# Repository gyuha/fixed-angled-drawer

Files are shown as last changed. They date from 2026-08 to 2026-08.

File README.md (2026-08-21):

# fixed-angled-drawer — 적층형 경사 필통

책상 모서리에 클램프로 고정하고, 같은 규격의 모듈을 위로 계속 쌓아 올리는 경사형 필통입니다.
FreeCAD 파이썬 스크립트 하나(`pen_holder.py`)가 모든 부품을 파라메트릭하게 생성하고, 치수·형상·출력성을 자체 검증합니다.

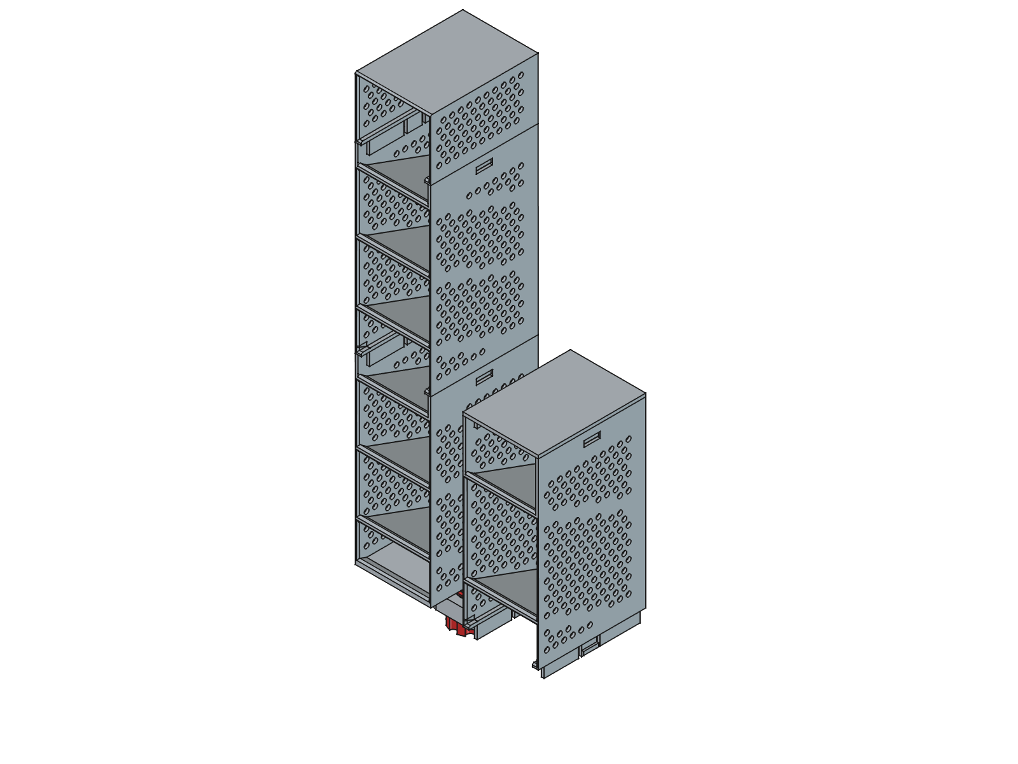
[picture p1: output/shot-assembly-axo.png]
조립 상태


## 특징

- **흔들리지 않는 고정** — 1단 뒷면에 책상 모서리를 감싸는 ㄷ자 클램프가 일체로 붙어 있고, 썸스크류로 상판을 물어 조입니다. 높이 쌓아도 흔들리지 않습니다.
- **무한 적층** — 모든 모듈의 높이(170mm)와 결합 인터페이스가 동일해서, 2칸·3칸 모듈을 어떤 순서로든 원하는 높이까지 쌓을 수 있습니다. 맨 위는 마감 모듈이나 평판 뚜껑으로 닫습니다.
- **적층 시 공간이 이어짐** — 적층 모듈의 하단이 열려 있어, 아래 모듈의 맨 위 칸과 공간이 연결됩니다. 긴 자·붓도 걸리지 않습니다.
- **서포트 없이 출력** — 뒷면을 베드에 대면 앞턱·클램프·결합부가 모두 자기지지 형상이라 서포트가 사실상 필요 없습니다.
- **측벽 타공** — 벌집 배열 타공이 측벽의 빈 영역에만 들어가 밋밋함을 덜고 무게를 줄입니다.

## 부품 구성

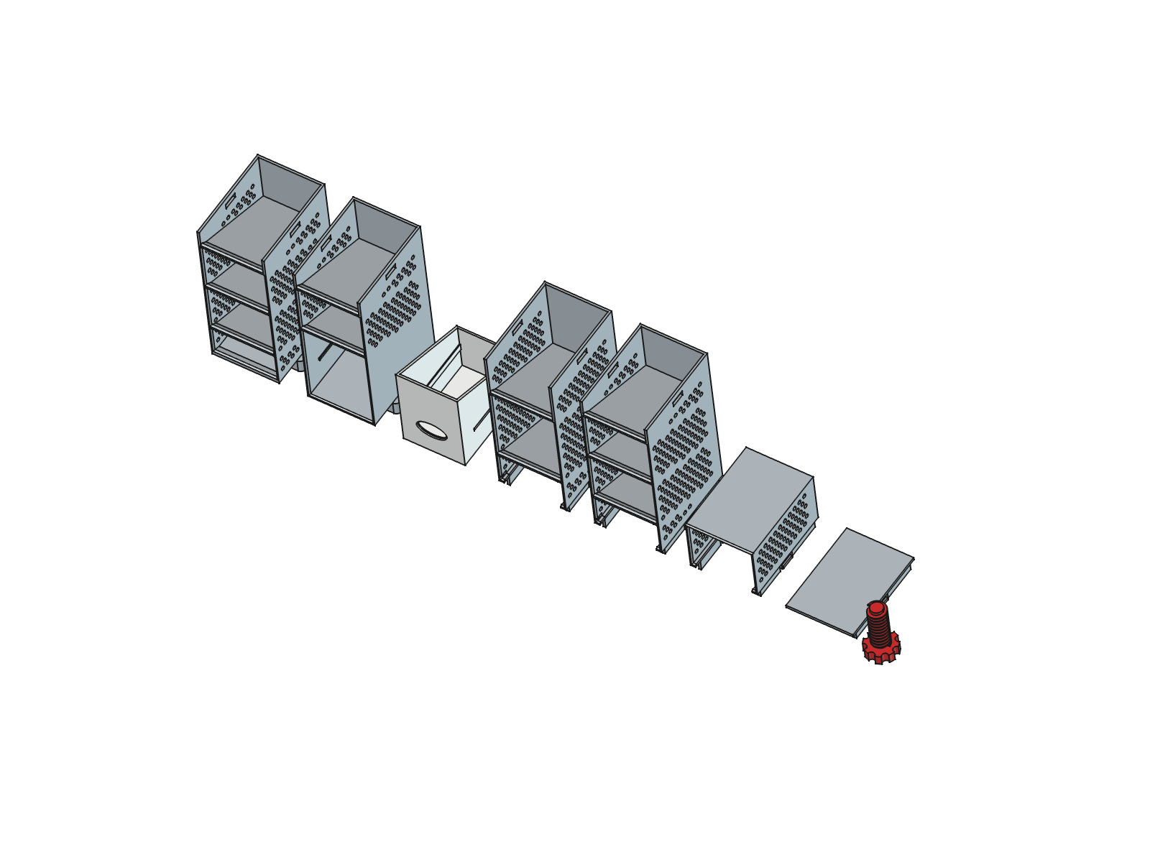
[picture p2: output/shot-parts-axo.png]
부품 8종


**부품 파일은 변형 폴더 안에 있습니다** — 아래 표의 STL은 `output/<변형>/` 기준 파일명입니다. 어느 변형을 고를지는 [변형 선택](#변형-선택)을 보세요.

| 부품 | STL | 높이 | 칸 수 | 역할 |
|---|-----|---|---|---|
| 1단 (바닥 모듈) | `tier1.stl` | 170mm | 3칸 | 맨 아래. 뒷면에 책상 클램프 + 암나사 일체형 |
| 1단 서랍형 | `tier1-drawer.stl` | 170mm | 위 2칸 + 서랍 1칸 | `tier1`의 최하단을 서랍으로 바꾼 변형. 클램프 동일 |
| 서랍 | `drawer.stl` | 앞 87.5→뒤 52.9mm | — | `tier1-drawer` 전용. 쐐기 상자, 용적 약 350cm³ |
| 적층 모듈 2칸 | `module2.stl` | 170mm | 2칸 (피치 85mm) | 긴 물건용 (자, 붓, 긴 가위) |
| 적층 모듈 3칸 | `module3.stl` | 170mm | 3칸 (피치 56.7mm) | 촘촘한 분류용 (펜, 지우개, 클립) |
| 마감 모듈 | `topmodule.stl` | 56.7mm | 바닥 없음 · 천장 일체 | 맨 위 마감용 한 부품. 윗면이 평평 |
| 평판 뚜껑 | `lid.stl` | 3mm | — | 2칸·3칸 모듈 위를 그대로 덮는 별도 뚜껑 |
| 썸스크류 | `thumbscrew.stl` | 59mm | — | 클램프 조임 나사 1개 |

최소 구성은 `tier1`(또는 `tier1-drawer` + `drawer`) + `thumbscrew`이고, 원하는 높이만큼 `module2`/`module3`을 추가로 출력해 쌓습니다. **1단은 `tier1`과 `tier1-drawer` 중 하나만 고르면 됩니다** — 둘은 같은 자리에 들어가는 대체 부품입니다.

**서랍형 1단 (`tier1-drawer` + `drawer`)**

맨 아래 칸이 열린 경사 칸 대신 서랍이 됩니다. 서랍은 경사 천장을 따라가는 **쐐기 상자**라 앞이 높고 뒤가 낮으며(87.5→52.9mm), 앞판이 개구 전체 높이를 덮어 안쪽을 최대로 씁니다.

- **손가락 개구**: 앞판의 가로 타원 30×16mm. 위치는 **빈 서랍의 무게중심 높이**입니다 — 위에서 당기면 무게중심보다 위를 당기게 되어 서랍이 기울고 마찰이 17~26% 늘어나기 때문입니다. 개구 모서리는 손가락이 아프지 않도록 r1.0으로 굴렸습니다.
- **가드 레일**: 홈은 서랍 측벽, 리브는 본체 측벽에 있습니다. 앞에서 깊이의 1/5(19mm) 들어간 지점부터 시작해 **앞면에는 드러나지 않고**, 깊이의 4/5 구간을 안내합니다. 76mm까지 빼도 앞이 처지지 않고, 그보다 더 빼면 그대로 분리됩니다(청소·비우기 용이).
- 서랍이 닿는 면이라 **서랍과 서랍 구간에는 타공이 없습니다.**

**맨 위 마감 — 두 가지 방법**

1. **마감 모듈(`topmodule`)을 올린다** — 천장이 일체로 붙은 한 부품이라 이것만 얹으면 끝납니다. 바닥이 없어 아래 모듈의 맨 위 칸과 공간이 이어지고(그만큼 깊은 수납), 자신의 천장이 그 공간을 덮습니다. 스택 높이는 56.7mm만 늘어납니다.
2. **평판 뚜껑(`lid`)만 덮는다** — 높이를 3mm만 더하는 가장 얇은 마감입니다. 모듈 바닥과 똑같은 스냅 구조라 2칸·3칸 모듈 위에 그대로 딸깍 걸립니다.

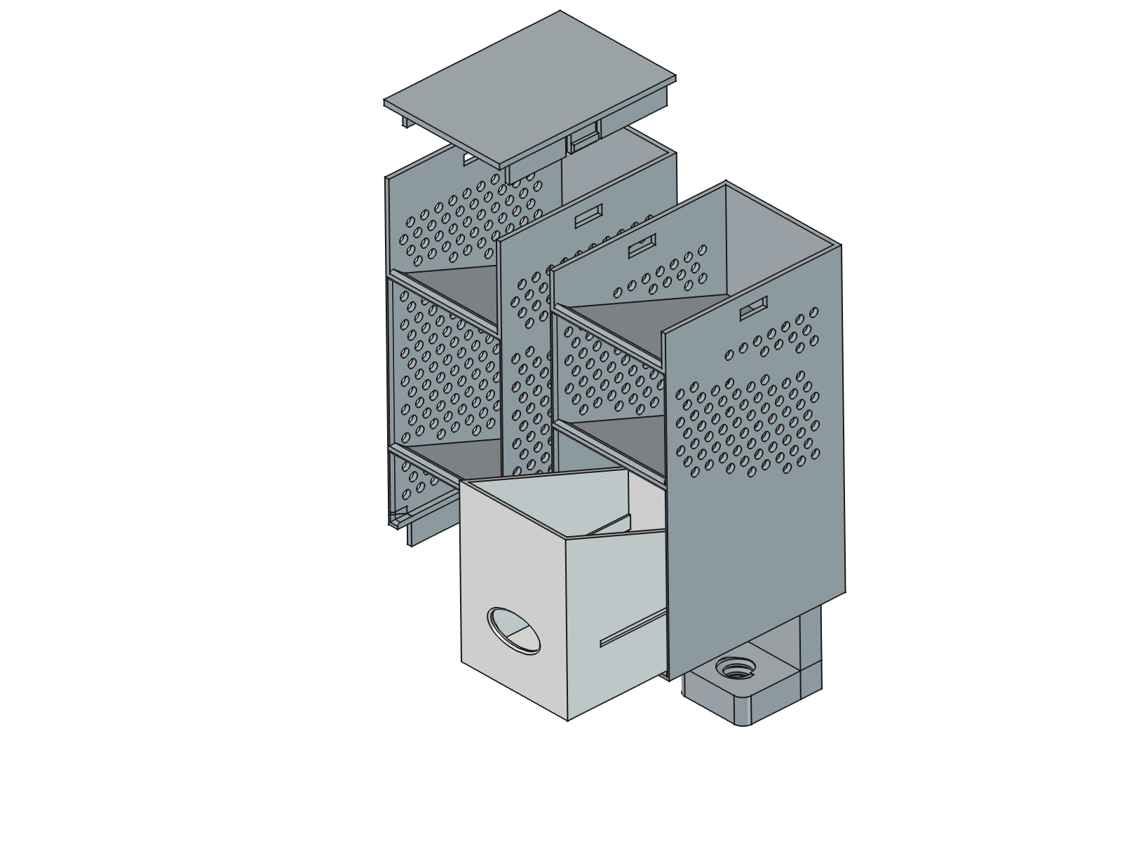
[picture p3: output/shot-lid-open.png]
뚜껑 분해도


위 그림은 2칸 모듈 위에서 뚜껑을 들어 올린 모습(왼쪽)과 서랍을 빼낸 모습(오른쪽, 흰색)입니다. 뚜껑 아래로 내려온 스냅 스커트가 모듈 상단의 캐치 창에 걸려 고정됩니다 — 모듈끼리 쌓이는 방식과 완전히 동일합니다.

> **⚠ 벽 두께 2.4mm판과 이전 3.0mm판은 섞어 쓸 수 없습니다.**
> 벽 두께는 적층 인터페이스의 기준선이라, 3.0mm판 모듈을 2.4mm판 위에 올리면 스커트가 좌우 각 0.85mm 헐거워지고(기존 0.25mm) 스냅 물림이 1.55 → 0.95mm로 줄어 흔들립니다. 한 스택은 같은 버전으로만 구성하세요. 3.0mm판이 필요하면 `WALL = 3.0`, `BOT_T`·`SHELF_T = 4.0`으로 되돌려 재생성하면 됩니다.

## 변형 선택

루트에서 스크립트를 한 번 실행하면 **폭 × 두께 조합 4가지**가 각자의 폴더에 생성됩니다. 폴더명에 폭과 벽 두께가 들어 있어 파일만 받아도 어느 버전인지 알 수 있습니다.

| 폴더 | 폭 | 벽 / 선반·바닥 | 세트 재료 (실측) | 언제 고르나 |
|---|-----|---|---|---|
| **`output/w70-wall2.4/`** | 70mm | 2.4 / 3.0mm | **511cm³ · 634g** | **기본 권장** — 가장 적게 들고 충분히 튼튼합니다 |
| `output/w80-wall2.4/` | 80mm | 2.4 / 3.0mm | 548cm³ · 680g | 폭이 넓은 편을 원할 때 |
| `output/w70-wall3.0/` | 70mm | 3.0 / 4.0mm | 601cm³ · 745g | 이미 3.0mm판을 쓰고 있어 섞어 써야 할 때 |
| `output/w80-wall3.0/` | 80mm | 3.0 / 4.0mm | 646cm³ · 801g | 폭 80mm + 3.0mm판 |

"세트"는 실사용 한 세트(1단서랍형 + 서랍 + 3칸 모듈 + 마감 모듈 + 썸스크류) 기준입니다.

**한 스택은 같은 폴더의 부품으로만 구성하세요.** 벽 두께가 적층 인터페이스의 기준선이라 2.4mm판과 3.0mm판을 섞으면 흔들립니다(위 경고 참고). 폭이 다른 것끼리도 당연히 섞이지 않습니다.

## 치수 사양

| 항목 | 값 |
|---|-----|
| 모듈 외형 (폭 × 깊이 × 높이) | 70 × 100 × 170mm |
| 마감 모듈 (천장 포함) | 70 × 100 × 56.7mm (= 3칸 모듈의 한 칸) |
| 서랍 (쐐기, 외형) | 63.2 × 95 × 앞 87.5→뒤 52.9mm, 용적 약 350cm³ |
| 서랍 공차 / 레일 공차 | 좌우 각 0.4 · 상하 0.5mm / 상하 각 0.3 · 깊이 0.4mm |
| 선반 경사각 | 수평 대비 20° |
| 벽 두께 / 바닥판 / 선반 | 2.4 / 3 / 3mm |
| 앞턱 | 높이 3mm, 기저 8mm 램프 (베드 대비 53.5°) |
| 타공 | Ø4.5mm, 피치 8mm 벌집 배열 |
| 클램프 개구 | 40mm |
| 체결 가능 상판 두께 | 5 ~ 40mm (나사가 아래턱 위로 35mm 올라옴) |
| 나사 규격 | 외경 18.5 / 골 12.7 / 피치 4 / 나사부 47mm |
| 적층 공차 / 나사 공차 | 0.25 / 0.4mm |
| 1단 전체 높이 (클램프 포함) | 224mm |

## 출력 가이드 (FDM)

**출력 방향이 가장 중요합니다. 통 부품은 모두 뒷면(등)을 베드에 붙여 눕혀서 출력하세요.** 이 방향에서만 클램프·앞턱·결합부가 모두 자기지지가 되어 서포트가 필요 없습니다.

| 부품 | 놓는 방향 | 그 방향의 서포트 면적 | 다른 방향 (참고) |
|---|---|---|---|
| `tier1` | 뒷면 아래로 | 3,641mm² | 직립 28,849 / 앞면 17,117 |
| `tier1-drawer` | 뒷면 아래로 | 1,910mm² | 직립 21,936 / 앞면 14,269 |
| `drawer` | **바닥을 베드에** | 430mm² | 뒷면 아래로 놓으면 4,468 |
| `module2` | 뒷면 아래로 | 4,077mm² | 직립 17,435 / 앞면 14,753 |
| `module3` | 뒷면 아래로 | 3,713mm² | 직립 23,696 / 앞면 14,165 |
| `topmodule` | 뒷면 아래로 | 1,562mm² | 직립 8,356 / 앞면 4,972 |
| `lid` | **뒤집어 평판이 베드에** | 50mm² | 그대로 놓으면 6,622 |
| `thumbscrew` | 손잡이 아래로 | 754mm² (나사산 하면) | — |

수치는 하향면 45° 기준으로 STL에서 광선 투사로 실측한 값입니다(폭 70mm 기준). 권장 방향에 남는 면적은 **Ø4.5mm 타공 구멍의 상단 아치**와 **썸스크류 나사산 하면**뿐인데, 둘 다 FDM이 서포트 없이 처리하는 크기입니다. 슬라이서가 굳이 서포트를 넣으려 하면 오버행 임계값을 55°로 올리세요.

**서랍(`drawer.stl`)은 바닥을 베드에** 놓으세요 — 위가 열려 있고 상면 경사도 재료가 끝나는 방향이라 서포트가 필요 없습니다.

**뚜껑(`lid.stl`)만 방향이 다릅니다.** 평판 아래로 스냅 스커트가 튀어나온 모양이라 슬라이서에서 **뒤집어 평판이 베드에 닿게** 놓아야 합니다. 그대로 놓으면 서포트가 130배로 늘어납니다.

- **재료**: PLA / PETG 모두 무난합니다. 클램프에 조임 하중이 걸리므로 PETG나 ABS가 더 여유 있습니다.
- **레이어**: 0.2mm, 벽 3줄 이상 권장. 스냅 후크에 힘이 걸리므로 벽을 얇게 하지 마세요.
- **공차 조정**: 스냅이 너무 빡빡하거나 헐거우면 `CLEAR`(기본 0.25mm), 나사가 안 돌아가면 `THR_CLEAR`(기본 0.4mm)를 프린터에 맞춰 조정 후 재생성하세요.

## 출력 시간·재료 줄이기

전량 출력은 시간이 오래 걸립니다(30시간 사례). 효과가 큰 순서대로 정리했습니다.

**1. 필요한 부품만 뽑기 — 가장 큰 레버 (실측 −43%)**

`tier1`과 `tier1-drawer`는 **같은 자리에 들어가는 대체 부품**이고, `module2`/`module3`도 변형입니다. 8개를 다 뽑으면 조립에 쓰지 않는 부품이 포함됩니다.

| 무엇을 뽑나 | 재료 | PLA |
|---|---|-----|
| 8부품 전량 | 894cm³ | 1,109g |
| 실사용 한 세트 (1단서랍형+서랍+3칸+마감+나사) | **511cm³** | **634g** |

**2. 서포트 끄기**

이 모델은 방향만 맞으면 서포트가 필요 없습니다(부품별 실측 근거는 위 출력 가이드). 슬라이서에서 서포트가 `tree(auto)`로 켜져 있으면 타공 구멍 상단 같은 곳에 불필요한 서포트가 붙어 시간·재료·후처리가 모두 늘어납니다. **끄고 출력하세요.** 굳이 켜야 한다면 오버행 임계값을 55°로 올리세요.

**3. 레이어 높이 올리기**

이 부품들은 뒷면을 베드에 대면 대부분 수직 벽이라, 레이어를 0.2 → **0.28mm**로 올려도 외관 손실이 작습니다. 층 수가 줄어 시간이 크게 짧아집니다. — **주의: 이 프로젝트에서는 이 값을 실측하지 못했습니다**(아래 참고). 직접 슬라이싱해 확인하세요.

**4. 벽 두께에 맞춘 벽 줄 수**

벽이 2.4mm이므로 `wall_loops`를 **3**으로 두면 벽이 솔리드로 채워져 강성이 회복되고 갭 필 아티팩트가 사라집니다. 2로 두면 벽 안쪽에 0.7mm 정도의 희소 인필 층이 생깁니다.

**시간을 직접 재는 방법**

재료량은 이 저장소에서 STL 부피로 실측했지만, **출력 시간은 슬라이서 설정에 좌우되어 모델만으로는 알 수 없습니다.** BambuStudio는 CLI로 시간을 뽑을 수 있습니다(단, **GUI가 실행 중이면 잠금에 걸려 동작하지 않습니다** — 앱을 닫고 실행하세요).

```bash
/Applications/BambuStudio.app/Contents/MacOS/BambuStudio \
  --slice 0 --arrange 1 --outputdir /tmp/out --export-3mf /tmp/out/o.3mf output/w70-wall2.4/module3.stl
grep -aE "estimated printing time|total filament length" /tmp/out/*.gcode
```

## 조립 방법

1단을 책상 모서리에 걸고 썸스크류로 조인 다음, 모듈을 위에서 눌러 끼우는 순서입니다. 모듈의 바닥 스커트에 있는 스냅 돌기가 아래 모듈 상단의 캐치 창에 딸깍 걸립니다.

```
1단을 책상 모서리에 걸기 → 썸스크류를 아래턱 암나사에 조임 (상판 아래를 눌러 고정)
        ↓
모듈을 1단 위에 얹고 수직으로 누름 → 스냅 돌기가 캐치 창에 걸리며 딸깍 고정
        ↓
원하는 높이까지 모듈 반복 적층 (2칸·3칸 순서 자유)
        ↓
맨 위에 마감 모듈을 얹어 마감 (+56.7mm) 또는 평판 뚜껑만 덮기 (+3mm)
```

서랍형을 쓰신다면 1단 자리에 `tier1-drawer`를 놓고 `drawer`를 앞에서 밀어 넣으면 됩니다. 밀어 넣으면 뒷벽 2mm 앞에서 멈추고, 당기면 76mm까지 안내되다가 분리됩니다.

분리할 때는 위 모듈을 잡고 좌우 측벽을 살짝 벌리면서 위로 당깁니다. 반복 분해는 후크 마모를 유발하니 자주 바꿔 끼우지 않는 편이 좋습니다.

## 모델 재생성

파라미터를 바꾼 뒤 스크립트를 실행하면 검증을 거쳐 STL·FCStd가 다시 생성됩니다. 검증이 하나라도 실패하면 마지막 줄에 `VERIFICATION FAIL`이 찍히므로, 출력 전에 이 줄을 반드시 확인하세요.

```bash
# 모델 생성 + 검증 + STL/FCStd 내보내기 (헤드리스)
/Applications/FreeCAD.app/Contents/Resources/bin/freecadcmd pen_holder.py

# 스크린샷 PNG 5장 재생성 (GUI가 잠깐 떴다 닫힘)
/Applications/FreeCAD.app/Contents/MacOS/FreeCAD screenshot.py
```

```
파라미터 수정 → freecadcmd pen_holder.py → 변형 4종 × 전체 검증 → VERIFICATION PASS → 폴더별 STL·FCStd 출력
                                              ↓ 실패
                                        FAIL 항목 출력 (출력물 사용 금지)
```

검증 항목은 변형 파라미터 정합(`IN_D`), 유효 솔리드(8종), 바운딩박스, 마감 모듈 높이·바닥 개방·천장 일체, 나사·스냅 정합, 체결 가능 상판 두께, 클램프 구멍 주변 재료, 앞턱 자기지지 각도, 앞면 필렛, 타공 배치, 서랍 관련 7가지(끼움·깊이 정지·개구 크기와 무게중심 정렬·개구 모서리 라운딩·레일 끼움·레일 구간·타공 0), 벽 두께 대비 스냅 물림 가드입니다. **개수는 문서에 적지 않습니다** — 스크립트가 항목별로 PASS/FAIL을 찍고 마지막 줄에 종합 결과를 내므로 그 출력이 유일한 기준입니다.

### 주요 파라미터

모두 `pen_holder.py` 상단에 모여 있습니다.

| 파라미터 | 기본값 | 설명 |
|---|---|---|
| `W` / `D` / `H` | 70 / 100 / 170 | 모듈 외형. `H`는 전 부품 공통이어야 적층이 호환됩니다 |
| `TIER1_SLOTS` | 3 | 1단 칸 수 |
| `MODULE_SLOTS` | (2, 3) | 생성할 적층 모듈 변형. 예: `(2, 3, 4)`로 4칸 추가 |
| `ANGLE` | 20 | 선반 경사각 |
| `LIP` / `LIP_BASE` | 3 / 8 | 앞턱 높이와 램프 기저. `LIP_BASE > LIP` 필수 (자기지지 조건) |
| `PERFORATE` / `PERF_D` / `PERF_PITCH` | True / 4.5 / 8 | 측벽 타공 on/off·지름·간격 |
| `WALL` / `BOT_T` / `SHELF_T` | 2.4 / 3 / 3 | 벽·바닥·선반 두께. 더 낮추면 `snap wall guard` 검증이 걸립니다 |
| `CLEAR` / `THR_CLEAR` | 0.25 / 0.4 | 스냅 공차 / 나사 공차 |
| `OPENING` | 40 | 클램프 개구 — 책상 상판이 40mm보다 두꺼우면 키우세요 |
| `THR_LEN` | 47 | 나사부 길이. 이 값이 짧으면 얇은 상판에 나사가 닿지 않습니다 |
| `TOP_H` / `LID_T` | H/3 (56.7) / 3 | 마감 모듈 전체 높이 / 천장·뚜껑판 두께 |
| `DRAWER_CLEAR` / `DRAWER_V_CLEAR` | 0.4 / 0.5 | 서랍 좌우 각 / 상하 합 공차 — 빡빡하면 키우세요 |
| `RAIL_GROOVE_*` / `RAIL_RIB_*` | 1.4×3.0 / 1.0×2.4 | 레일 홈(서랍) / 리브(본체) 치수 |
| `RAIL_START` | 0.2 | 레일 시작 위치(깊이 비율). 앞에서 이만큼 비우고 4/5를 안내 |
| `PULL_W` / `PULL_H` | 30 / 16 | 손가락 개구 크기 (위치는 무게중심에서 자동 계산) |

## 파일 구조

```
pen_holder.py          모델 생성·검증·내보내기 (파라메트릭, 단일 소스, 변형 4종 일괄)
screenshot.py          기준 변형 FCStd → PNG 스크린샷 (FreeCAD GUI 필요)
LICENSE                코드 라이센스 (PolyForm Noncommercial 1.0.0)
LICENSE-MODELS         도면·모델 라이센스 (CC BY-NC-SA 4.0)
COMMERCIAL.md          상업 이용 안내 (허용 범위·문의 방법)
output/
  shot-*.png           스크린샷 5장 (기준 변형 기준, 부품·조립 3방향·분해도)
  w70-wall2.4/         ← 기준 변형
    tier1.stl  tier1-drawer.stl  drawer.stl
    module2.stl  module3.stl  topmodule.stl  lid.stl  thumbscrew.stl
    pen_holder.FCStd   FreeCAD 문서 (부품 나열 뷰 + 조립 뷰 배치)
  w80-wall2.4/         (같은 구성)
  w70-wall3.0/         (같은 구성)
  w80-wall3.0/         (같은 구성)
```

폭 80mm판은 더 이상 별도 폴더(`output-8cm/`)로 두지 않고 변형(`w80-*`)으로 함께 생성됩니다.

각 변형 폴더의 `*.stl`은 모두 원점 기준으로 내보내므로 슬라이서에 그대로 올리면 됩니다. `pen_holder.FCStd`의 부품 배치는 문서 안에서만 적용된 것이라 STL 좌표에 영향이 없습니다.

## 라이센스

**비상업적 이용은 무상, 상업적 이용은 별도 라이센스가 필요합니다.**

| 대상 | 라이센스 | 파일 |
|---|---|---|
| 소스 코드 (`pen_holder.py`, `screenshot.py`) | **PolyForm Noncommercial 1.0.0** | [LICENSE](LICENSE) |
| 도면·모델 (`output/` 전체의 STL·FCStd·3MF·렌더) | **CC BY-NC-SA 4.0** | [LICENSE-MODELS](LICENSE-MODELS) |

**자유롭게 하실 수 있는 것** — 개인·가정에서 쓰려고 출력하기, 친구에게 뽑아 무상으로 주기, 학교·도서관·메이커스페이스 등 교육·비영리 목적의 사용, 모델이나 스크립트를 고쳐서 비상업적으로 재배포하기(출처 표시 + 동일 조건 공개).

**별도 라이센스가 필요한 것** — 출력물 판매, 유료 서비스·제품의 일부로 제공, 상업적 주문 제작, 양산 원형 사용. 자세한 경계와 문의 방법은 [COMMERCIAL.md](COMMERCIAL.md)를 보세요. 경계가 애매하면 이슈로 물어보시면 됩니다.

```
"fixed-angled-drawer" by gyuha, licensed under CC BY-NC-SA 4.0.
https://github.com/gyuha/fixed-angled-drawer
```

## 참고 뷰

| 정면 | 측면 |
|---|---|
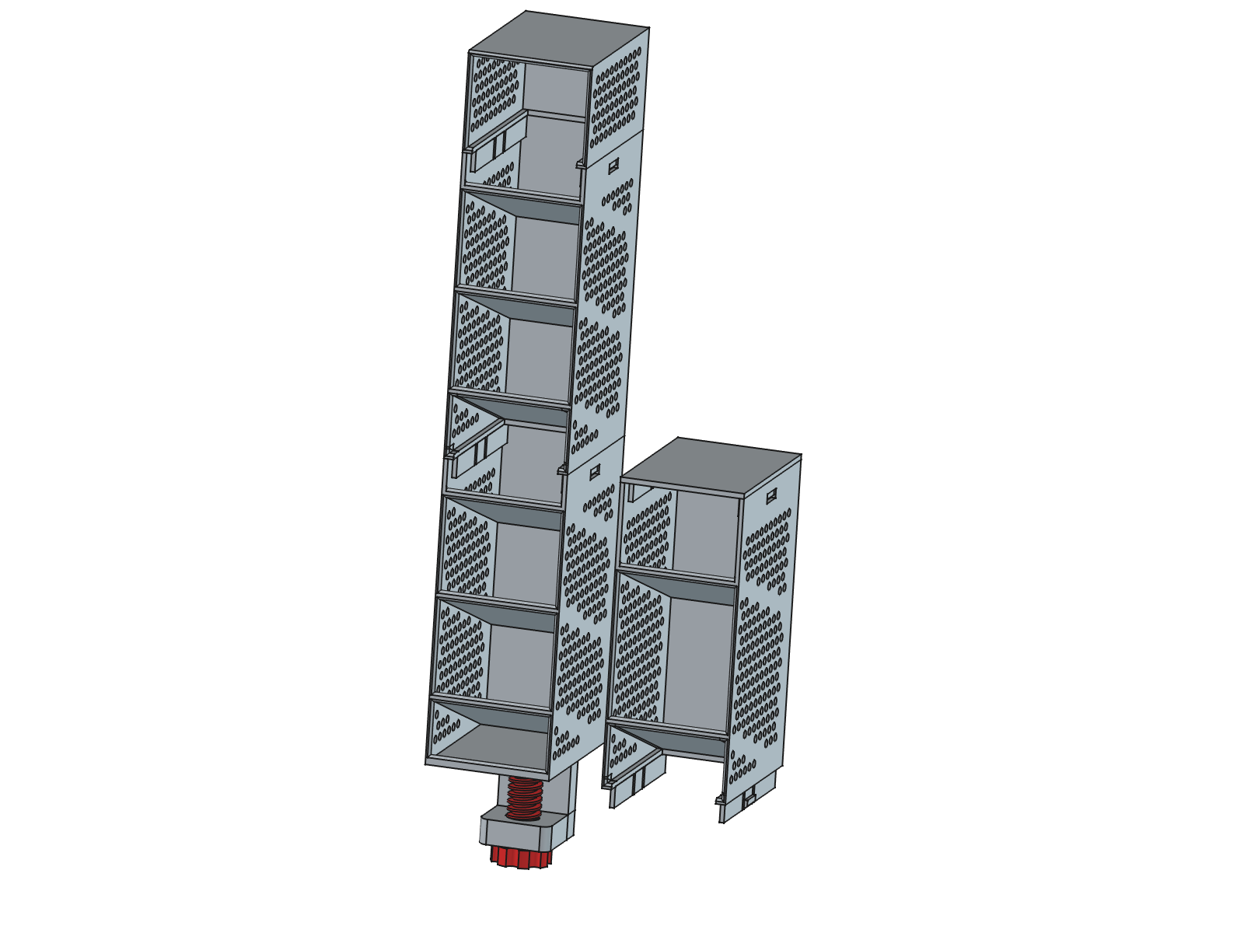
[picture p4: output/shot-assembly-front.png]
조립 정면
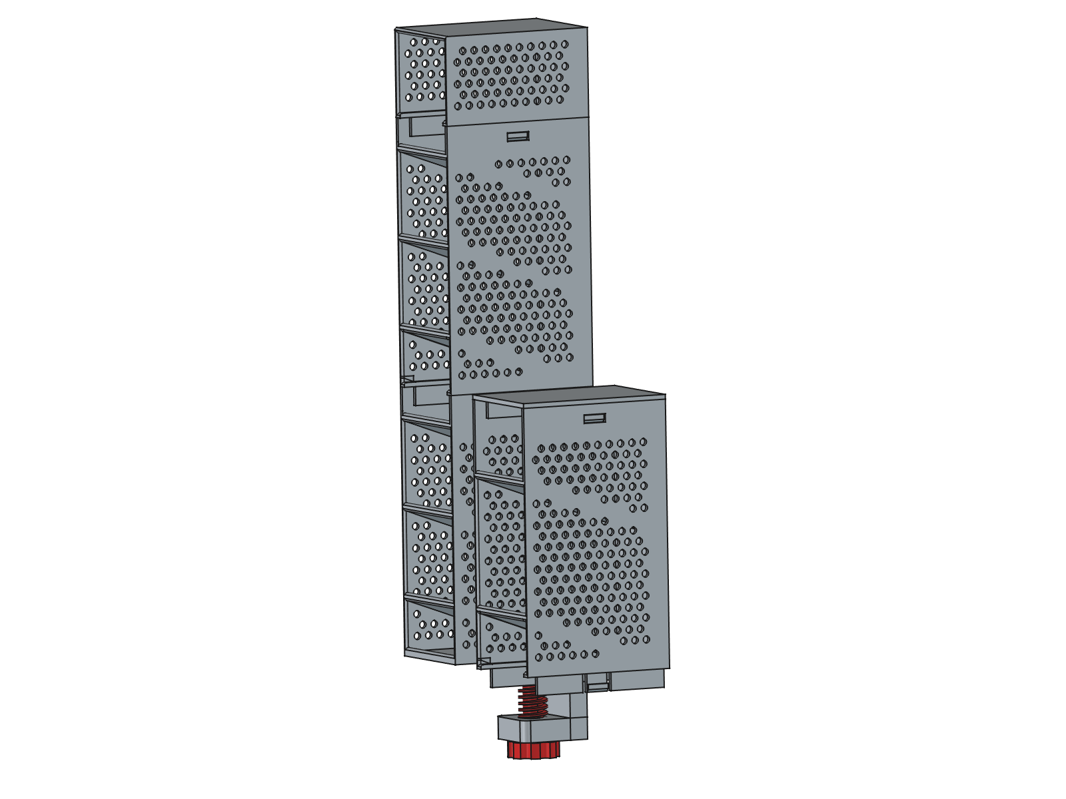
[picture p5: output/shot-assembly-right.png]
조립 측면
|  |  |

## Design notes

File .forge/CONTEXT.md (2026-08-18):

# CONTEXT — 용어집

## 적층 모듈 (stacking module)
경사 칸을 가진 필통 한 단위(외형 70×100×170mm). 바닥의 스냅 후크로 아래 모듈에, 상단의 캐치로 위 모듈에 연결되어 무한 적층된다. 칸 수가 다른 변형(2칸·3칸)이 있으나 높이와 결합 인터페이스가 같아 어떤 순서로든 섞어 쌓을 수 있다. 바닥이 열려 있어 아래 모듈의 맨 위 칸과 공간이 이어진다.

## 1단 (base tier)
맨 아래에 오는 모듈. 적층 모듈과 같은 본체·상단 캐치를 가지되, 바닥 스냅 후크 대신 뒷면에 클램프가 일체형으로 붙고 바닥은 막혀 있다. 경사 칸 3개.

## 마감 모듈 (top module)
스택 맨 위를 덮는 모듈. 천장이 일체로 붙어 윗면이 평평하고, 바닥은 열려 있어 아래 칸과 공간이 이어진다. 위에 아무것도 올라가지 않으므로 상단 캐치가 없다. 높이는 3칸 모듈의 한 칸과 같다.

## 평판 뚜껑 (lid)
적층 모듈 위를 덮는 얇은 평판 부품. 적층 모듈 바닥과 동일한 스냅 스커트를 가져 어느 모듈 위에도 그대로 결합한다. 마감 모듈 대신 높이를 거의 늘리지 않고 마감할 때 쓴다.

## 경사 칸 (angled slot)
모듈 내부의 수납 슬롯. 바닥 선반이 수평 대비 20° 기울어져 내용물이 뒤로 기대어 정리된다. 칸 수는 부품마다 다르고(2칸 또는 3칸), 칸 피치는 모듈 높이를 칸 수로 나눈 값이다.

## 앞턱 (front lip)
경사 칸 앞 끝의 낮은 턱. 내용물이 앞으로 미끄러져 나오는 것을 막는다. 뒷면을 향한 면이 자기지지 각도의 램프라 서포트 없이 출력된다.

## 서랍 구간 (drawer bay)
1단 변형(tier1-drawer)의 최하단에 있는 공간. 경사 선반을 들어내 바닥부터 위 선반 밑면까지가 통째로 열려 있고, 서랍이 앞에서 미끄러져 들어간다. 측벽에는 타공을 두지 않고(서랍이 닿는 면) 서랍을 안내하는 레일 리브가 붙는다.

## 서랍 (drawer)
서랍 구간에 끼워 쓰는 별도 부품. 위가 열린 쐐기 상자로, 경사 천장을 따라 앞이 높고 뒤가 낮아 경사 공간까지 수납에 쓴다. 앞판은 개구 전체 높이를 덮으며 모듈 앞면과 한 평면을 이루고(플러시 인셋), 당기면 완전히 빠진다. 앞판의 손가락 개구는 빈 서랍의 무게중심 높이에 두어 당길 때 기울어지지 않는다.

## 레일 (guide rail)
서랍을 안내하는 한 쌍의 요철. **홈은 서랍 측벽, 리브는 본체 측벽**에 있고, 홈이 리브의 상·하를 잡아 서랍을 빼낼 때 처지지 않게 한다. 앞에서 깊이의 1/5만큼 들어간 지점부터 시작해 앞면에는 드러나지 않으며, 깊이의 4/5 구간을 안내하다가 그보다 더 빼면 서랍이 분리된다.

## 스냅핏 클립 (snap-fit clip)
단(모듈) 사이 연결 방식. 위 모듈 바닥의 후크(hook)가 아래 모듈 상단의 캐치(catch) 구멍에 눌러 끼워져 딸깍 고정된다. 후크는 본체 일체형.

## 클램프 (desk clamp)
1단 뒷면의 ㄷ자 구조물. 책상 모서리를 감싸고 아래턱의 암나사에 썸스크류를 조여 상판 아래면을 눌러 고정한다. 개구(상판 물림 높이) 40mm, 체결 가능한 상판 두께는 5~40mm. 모듈 뒷면과 같은 평면에 맞춰져 뒷면 전체가 하나의 평면이다.

## 썸스크류 (thumbscrew)
클램프를 조이는 손잡이 달린 나사. 외경 18.5mm, 피치 4mm, 나사부 47mm, 손잡이 Ø32.6mm. 나사부 길이가 곧 체결 가능한 상판 두께 범위를 결정한다.

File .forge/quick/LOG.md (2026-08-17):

# fg-quick 로그

## 2026-08-18 — 클램프 폭 40mm로 축소
- 요청: 체결부가 필요 이상으로 넓음, 양옆 10mm씩 축소. 문제 있으면 알릴 것
- 검토: 나사 구멍(Ø19.3) 양옆 재료 20.4→10.3mm, 뒷판 단면계수 1440→960mm³. 가혹 조건(3kg·팔길이 100mm)에서 굽힘응력 3.1MPa로 PLA 항복 대비 16배 여유 → 문제 없음
- 결정: CLAMP_W 60→40mm. 더 줄이면 구멍 주변이 위험해지므로 '구멍 주변 재료 ≥8mm' 검증 항목 추가
- 결과: done (검증 21항목 PASS. STL 실측: 클램프 x 15~55(폭 40), 앞면 x 20~50으로 r5 필렛 유지 확인)

## 2026-08-18 — 썸스크류 빨강 표시
- 요청: 스크류 색상을 빨강으로, 스샷 재생성
- 결정: 색상은 GUI 속성(ViewObject)이라 헤드리스 pen_holder.py에서는 설정 불가 → screenshot.py에서 이름에 screw가 든 객체에 적용하고, 문서를 저장해 FCStd를 열어도 빨강이 유지되게 함
- 결과: done (thumbscrew·asm_screw 둘 다 적용, PNG 5장 재생성·육안 확인. 첫 렌더에 초록 선택 하이라이트가 찍혀 clearSelection 추가 후 재생성)

## 2026-08-18 — 클램프 아래턱 10mm 축소 + 앞 끝 r5 필렛
- 요청: 책상 체결부가 너무 많이 나와 있음, 표시 부분 10mm 축소 + 잘린 끝 양 모서리에 r5 필렛
- 결정: JAW_REACH 55→45mm(나사 구멍 앞으로 재료 7.4mm 남음). 필렛은 아래턱 앞 끝의 좌우 세로 모서리 2개에 r5, 나사산 절삭 전에 적용해 OCC 실패 회피
- 결과: done (검증 20항목 PASS. STL 실측: 아래턱 y 55~100, 각 코너 정점 0개·r5 원호 58점·앞면 x 10~60으로 필렛 적용 확인)

## 2026-08-18 — 썸스크류 25mm 연장 (얇은 상판 체결 불가 수정)
- 요청: 책상이 얇아 체결이 안 됨, 스크류 높이 2.5cm 증가
- 원인: 샤프트 24mm - 아래턱 14mm = 턱 위 돌출 10mm뿐 → 개구 40mm 대비 30mm 미만 상판에는 나사가 닿지 않음 (README의 "18~25mm 대응"은 틀린 값이었음)
- 결정: THR_LEN 22→47mm, 샤프트를 THR_LEN+2로 파라미터화(24 하드코딩 제거). 같은 결함을 다시 놓치지 않도록 '체결 가능 상판 두께' 검증 항목 추가
- 결과: done (검증 20항목 PASS — 체결 5~40mm, 나사 전체 높이 59mm 실측, 스크린샷 재생성, README 오기재("18~25mm 대응") 정정)

## 2026-08-17 — 뚜껑 분해 뷰 추가
- 요청: 뚜껑이 보이는 스샷으로 README 구성
- 결정: 조립 뷰에서 뚜껑이 '평평한 윗면'으로만 보여 별개 부품임이 안 드러남 → exp_ 접두어 분해 배치(뚜껑을 35mm 띄움) 추가하고 screenshot.py를 접두어 3그룹(parts/asm_/exp_)으로 확장, shot-lid-open.png를 README 마감 절에 배치
- 결과: done (PNG 5장 생성·분해도 육안 확인, README 이미지 5개 참조 무결성 확인, 검증 19항목 PASS)

## 2026-08-17 — 폭 80→70mm 변경 (8cm판은 output-8cm으로 보존)
- 요청: 출력해보니 폭이 넓음. 기존 output을 output-8cm으로 백업하고 폭 7cm 도면 생성
- 결정: output 디렉터리를 통째로 output-8cm으로 이동(사용자의 fixed-drawer.3mf도 8cm 산출물이라 함께 이동), W=70.0으로 바꿔 output에 새로 생성. 다른 파라미터는 W에 종속되거나 폭과 무관해 그대로
- 결과: done (검증 19항목 PASS, STL 6종 폭 70.00mm 실측 확인, 스크린샷 재생성, README 치수/파일구조 갱신)

## 2026-08-17 — 마감 모듈에 천장 일체화
- 요청: 마감 모듈 자체에 뚜껑이 있었으면 함. 지금의 분리형 뚜껑은 2칸 모듈용으로 유지
- 결정: topmodule을 높이 56.7mm(=TOP_H) 한 부품으로 — 상단 3mm 천장 일체, 바닥 개방 유지, 위에 아무것도 안 올라가므로 캐치 창 제거. lid.stl은 그대로 두고 조립 뷰에 module2+lid 예시 추가
- 결과: done (검증 19항목 PASS — 바닥 개방·천장 일체 좌표 확인, 스크린샷 재생성·육안 확인, README/독스트링 갱신)

## 2026-08-17 — 마감용 최상단 모듈 + 평평한 뚜껑
- 요청: 최상단에 쓰는 마감 모듈, 뚜껑 닫았을 때 3칸 모듈의 1칸 높이(56.7mm), 평평한 뚜껑
- 결정: 얕은 트레이(높이 53.7mm, 평바닥·앞턱 램프·개방 전면)+평판 뚜껑(3mm). 뚜껑은 모듈 바닥과 동일한 스냅 스커트를 그대로 써서 어느 모듈 위에도 덮이게 함. 닫은 높이 53.7+3=56.7=H/3
- 후속: 마감 모듈은 바닥 불필요(아래 칸과 연결, 뚜껑이 그 공간을 덮음) → 평바닥·앞턱 제거하고 열린 칼라로 변경, 측벽 FLANGE 레일만 존치
- 결과: done (검증 19항목 PASS — 바닥 개방·레일 존치 확인 포함, 스크린샷 재생성·육안 확인, README/독스트링 갱신)

## 2026-08-17 — README.md 작성
- 요청: README 작성 + 스크린샷 배치
- 결정: output/shot-*.png 4장을 그 자리에서 참조(재생성 시 문서도 자동 최신화). 부품·치수·출력 가이드·조립·파라미터·재생성 절차 수록. pen_holder.py 독스트링의 낡은 산출물 목록도 함께 정정
- 결과: done (이미지 경로 4개 존재 확인, 독스트링 수정 후 재실행 VERIFICATION PASS)

## 2026-08-17 — FCStd 배치 (스크린샷용)
- 요청: FreeCAD 모델에서 스샷 찍을 수 있게 배치
- 결정: 4부품이 원점에 겹쳐 있던 문제 → 부품 나열 뷰(X방향 간격)와 조립 뷰(tier1+module3 적층+썸스크류 체결)를 같은 FCStd에 배치. Placement만 이동하므로 STL은 원점 유지. 추가로 screenshot.py(GUI 실행)로 PNG 4장 자동 생성
- 결과: done (PNG 4장 생성·육안 확인, STL 원점 유지 확인. Gui.showMainWindow는 1.1.3에 없어 제거)

## 2026-08-17 — 앞턱 단차 제거 (서포트 최소화)
- 요청: 앞턱 단차 때문에 서포트가 과도함, 서포트 없을 정도로 최소화
- 결정: 광선투사 분석으로 뒷면-아래 방향 기준 원인 3개 확인 → 앞턱을 수직 단차(6mm)에서 45°+ 자기지지 램프(높이 3mm·기저 8mm)로, 뒷면 스커트 판 제거(측면 스커트가 깊이 위치 결정 담당). 타공 구멍 상단 아치는 Ø4.5 브리징 범위로 판단해 유지
- 결과: done (검증 13항목 PASS·램프 53.5°. 서포트 면적 앞턱 1669→104·2050→104mm², 스커트 882→60mm², 합계 6100→3713 / 5587→3641mm²)

## 2026-08-17 — 측벽 타공 패턴
- 요청: 옆면이 밋밋하지 않게 타공 구멍, 단 옆면의 빈 곳에만
- 결정: Ø4.5·피치 8mm 스태거드 배열, X관통 원기둥으로 양 측벽 동시 타공. 선반 슬래브 띠(±1.5 여유)·캐치 창·상하 결합부·앞뒤 가장자리 회피, 부품별 칸 배치에 맞춰 자동 산출
- 결과: done (검증 12항목 PASS — 2칸 169·3칸 153개, 측벽 투영으로 회피 영역 확인)

## 2026-08-17 — tier1 3칸화 + 모듈 2칸/3칸 변형
- 요청: 바닥 모듈(1단)을 3칸으로, 적층 모듈은 2칸·3칸 두 가지로
- 결정: 칸 수를 make_body 파라미터로. 모든 부품 높이 170 유지(적층 호환), 3칸 피치 56.7mm. 산출물 4종: tier1(3칸)·module2·module3·thumbscrew, 기존 module.stl은 module2.stl로 대체
- 결과: done (검증 11항목 PASS, 단면 분석으로 부품별 선반 수 2/3/3 확인)

## 2026-08-17 — 클램프를 뒷면과 플러시로 (FDM 출력 대응)
- 요청: 연결(클램프) 부위를 뒷면과 맞춰 등을 대고 평평하게 출력되게, 두께 유지·튼튼하게
- 결정: 뒷판을 y 88~100(안쪽)으로 이동, PLATE_UP 보강 제거(칸 침범 방지), 접합 단면 60×12mm로 강성 유지. 책상 물림 깊이는 뒷면에서 12mm 안쪽부터
- 결과: done (검증 10항목 PASS, 단면 점검으로 뒷면 전체 단일 평면 확인)

## 2026-08-17 — 적층 연결부 필렛 제외
- 요청: 위아래 연결 부위(상단 테두리·하단 레일/스커트)에는 필렛 금지, 결합이 자연스럽게
- 결정: z=0 이하 또는 z=170에 닿는 모서리를 필렛 대상에서 제외. 부분 필렛 불가로 측벽 앞 세로 모서리 필렛은 포기, 선반·턱·개구부 필렛만 유지
- 결과: done (검증 10항목 PASS + STL 정점 점검: 연결부 각짐 복원·중간 필렛 유지 확인)

## 2026-08-17 — 앞쪽 모서리 필렛
- 요청: 앞쪽 모서리들에 필렛을 줘서 부드럽게 사용할 수 있게
- 결정: y<벽두께 구간의 모서리 일괄 선택, 반경 1.4mm(벽 3mm 제약) + 실패 시 반경 하향 사다리. module·tier1 모두 적용
- 결과: done (module r=1.4·tier1 r=1.4 적용, freecadcmd 검증 10항목 PASS)

## 2026-08-17 — 모듈 하단 개방 (적층 시 아래 칸과 공간 연결)
- 요청: 하단 포켓의 바닥판·앞턱을 비워 아래 모듈 상단 칸과 이어지게
- 결정: 모듈만 개방(tier1은 바닥 유지), 측면 스커트 부착용 바닥판 3mm 레일은 존치
- 결과: done (freecadcmd 재검증 9항목 PASS, 단면 점검으로 개방·레일 확인)

## 2026-08-17 — 모듈 하단을 전면 개방 수납 포켓으로 변경
- 요청: 모듈 하단(전면 밴드 + 숨은 쐐기)을 공간 활용이 되는 수납 공간으로
- 결정: 바닥판 위 평평한 포켓 + 기존 칸과 동일한 6mm 앞턱, 천장은 최하단 경사 선반 밑면. tier1도 공유 본체라 자동 반영
- 결과: done (freecadcmd 재검증 9항목 PASS, 단면 점검으로 포켓 개방 확인)

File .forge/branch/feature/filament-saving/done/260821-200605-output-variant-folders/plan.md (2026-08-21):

<!-- forge-slug: output-variant-folders -->
<!-- task: 4 -->
<!-- tdd: off -->
# 4개 변형(폭 × 두께)을 폴더별로 생성

## 목표 / 비목표
- 목표: 루트에서 `pen_holder.py`를 **한 번 실행**하면 폭 70/80mm × 두께 세트 2종(얇은판/두꺼운판)의 **4가지 변형**이 각자의 폴더에 생성된다. 각 변형은 기존 검증 32항목을 모두 통과한다.
- 비목표: 부품 형상·인터페이스 변경, 변형 개수 확장 구조(4종 고정으로 충분), 변형별 렌더 생성(기준 1종만), 변형 간 자동 비교 리포트, 릴리스 자산 재업로드.

## 확정 사양 (그릴링 합의)
- **폴더 구조**: `output/` 아래 **한 단계 평면**. 폴더명에 폭과 벽 두께가 모두 들어가 파일이 밖으로 나가도 출처가 분명하도록 한다.
  ```
  output/
    w70-wall2.4/   ← 기준 변형 (현재 output/ 내용에 대응)
    w70-wall3.0/
    w80-wall2.4/
    w80-wall3.0/   ← 옛 output-8cm/ 에 대응
  ```
- **변형 정의** (두께는 세트로 움직인다):
  | 폴더 | `W` | `WALL` | `BOT_T` | `SHELF_T` |
  |------|-----|--------|---------|-----------|
  | `w70-wall2.4` | 70 | 2.4 | 3.0 | 3.0 |
  | `w80-wall2.4` | 80 | 2.4 | 3.0 | 3.0 |
  | `w70-wall3.0` | 70 | 3.0 | 4.0 | 4.0 |
  | `w80-wall3.0` | 80 | 3.0 | 4.0 | 4.0 |
  `wall3.0`은 **예전 두께 전체 복원**이다(선반·바닥 4.0 포함). 적층 호환을 결정하는 것은 벽 두께뿐이므로 폴더명에는 벽 두께만 넣는다.
- **구현 제약(그릴링 중 확인)**: `WALL`에서 파생되는 모듈 상수는 `IN_D = D - WALL` **하나뿐**이고 `W`·`BOT_T`·`SHELF_T`에서 파생되는 것은 없다. 따라서 변형 전환은 `W`·`WALL`·`BOT_T`·`SHELF_T`·`IN_D` 다섯 개만 다시 세팅하면 된다 — 파생 상수를 놓쳐 조용히 틀린 형상이 나오는 것을 막기 위해 **변형마다 `IN_D == D - WALL` 검증**을 넣는다.
- **기존 파일 이관**: `output-8cm/`은 폐지하고 그 자리는 `w80-wall3.0/`으로 새로 생성한다(현재의 모든 기능이 들어간 형상). 직접 만드신 슬라이서 프로젝트 2개는 **삭제하지 않고** 대응 폴더로 옮긴다 — `output/fixed-drawer.3mf` → `w70-wall2.4/`, `output-8cm/fixed-drawer.3mf` → `w80-wall3.0/`.
- **렌더**: 기준 변형(`w70-wall2.4`) 5장만 유지하고 **위치는 `output/` 루트 그대로** 둔다(README 링크 유지, 벽 2.4/3.0은 렌더에서 구분되지 않아 중복). `screenshot.py`가 읽는 FCStd 경로는 기준 변형 폴더로 바꾼다.

## 진실의 원천
- 용어: `.forge/CONTEXT.md`의 적층 모듈 · 스냅핏 클립 · 서랍 구간 · 클램프
- 관련 ADR: 없음 (폴더 배치·변형 테이블은 되돌릴 수 있어 기준 미달)
- 완료 정의(DoD): (a) 루트에서 `freecadcmd pen_holder.py` 한 번 실행으로 4폴더가 만들어지고 각 폴더에 STL 8개 + FCStd 1개가 존재, (b) **4변형 각각 검증 32항목 + `IN_D` 정합 항목 PASS**가 출력, (c) 변형별 세트 재료량이 실측되어 서로 다름이 확인됨(폭·두께가 실제로 반영됐다는 증거), (d) 사용자 3mf 2개가 손실 없이 대응 폴더에 존재하고 `output-8cm/`은 없음, (e) README의 파일 구조·부품 표·경로가 4변형 구조로 갱신되고 옛 경로(`output/tier1.stl` 등) 잔존 0, 이미지 링크 무결.

## 작업 조각
- [ ] S1. 변형 테이블 + 전환 함수 + 4회 순회 생성 — `VARIANTS`(폴더명·W·WALL·BOT_T·SHELF_T), `set_variant()`(다섯 상수 재세팅), `main()`이 변형마다 폴더를 만들어 생성·검증·내보내기. `IN_D` 정합 검증 추가 — 완료 기준: 4폴더 × (STL 8 + FCStd 1) 생성, 각 변형 검증 전항목 PASS, 변형별 세트 재료량이 서로 다르게 실측됨 (예상 실행 시간 5~7분)
- [ ] S2. 기존 파일 이관 + 도구 경로 — `output-8cm/` 폐지, 3mf 2개를 대응 폴더로 이동, 렌더 5장은 루트 유지, `screenshot.py`의 FCStd 경로를 `output/w70-wall2.4/`로 변경하고 렌더 재생성 — 완료 기준: 3mf 2개가 대응 폴더에 존재, `output-8cm/` 없음, 렌더 5장 재생성되고 README 이미지 링크 무결 (depends: S1)
- [ ] S3. README 갱신 — 파일 구조를 4변형으로, "어느 폴더를 뽑아야 하는가" 안내(기본은 `w70-wall2.4`, 이미 3.0mm판을 쓰고 있으면 `*-wall3.0`), 부품 표·재생성 절의 경로 정정, 변형별 재료량 실측 표 추가 — 완료 기준: 4변형 표와 선택 안내가 문서에 존재, 옛 경로 잔존 0 (depends: S2)

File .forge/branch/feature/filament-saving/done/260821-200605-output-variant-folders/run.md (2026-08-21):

<!-- forge-slug: output-variant-folders -->
# 실행 기록 — 4개 변형(폭 × 두께)을 폴더별로 생성

## 조각별 결과
- S1 변형 테이블 + 전환 함수 + 4회 순회 생성, `IN_D` 정합 검증 추가 — ✅ 계획대로
- S2 기존 파일 이관(`output-8cm/` 폐지, 3mf 2개 이동) + `screenshot.py` 경로 변경·렌더 재생성 — ✅ 계획대로
- S3 README 4변형 구조 반영 — ⚠ 계획에 없던 판단 하나: 문서에서 검증 항목 **개수 표기를 제거**

## 계획대로 된 것
- 루트에서 한 번 실행하면 4폴더가 생성된다: `output/{w70,w80}-wall{2.4,3.0}/`, 각 폴더에 STL 8개 + FCStd 1개.
- **변형당 33항목 × 4변형 = 132개 전부 PASS, FAIL 0.** 신규 `variant params` 항목이 변형마다 `IN_D == D - WALL`을 확인한다.
- 변형별 세트 재료량이 서로 다르게 실측됐다 — 폴더만 생기고 내용이 같은 사고가 아님을 증명한다:
  | 폴더 | 세트 재료 |
  |------|-----------|
  | w70-wall2.4 | 510.9cm³ (634g) |
  | w80-wall2.4 | 548.3cm³ (680g) |
  | w70-wall3.0 | 600.8cm³ (745g) |
  | w80-wall3.0 | 646.2cm³ (801g) |
- 사용자 슬라이서 프로젝트 2개를 **삭제하지 않고** 대응 폴더로 이동: `output/w70-wall2.4/fixed-drawer.3mf`, `output/w80-wall3.0/fixed-drawer.3mf`. `output-8cm/`은 폐지.
- 렌더 5장은 `output/` 루트에 유지되어 README 이미지 링크가 그대로 살아 있다(확인). `screenshot.py`는 `REF_VARIANT = "w70-wall2.4"`의 FCStd를 읽는다.

## 현장 결정 (계획에 없던 판단)
- **문서에서 검증 항목 개수 표기를 제거했다.** 이번에 개수를 세려다 정규식 추정이 32/34로 흔들렸고, 이 프로젝트에서 이미 두 번(31↔32) 문서와 실제가 어긋났다. 스크립트가 항목별 PASS/FAIL과 종합 결과를 찍으므로 숫자를 문서에 중복 관리할 이유가 없다 — "그 출력이 유일한 기준"이라고 명시했다.
- `set_variant()`가 서랍 껍데기 캐시(`_SHELL`)와 `_DRAWER_INFO`를 비운다. 캐시가 변형 간에 남으면 이전 변형의 무게중심·개구 위치가 그대로 재사용되어 조용히 틀린 형상이 나온다.
- FCStd 문서명을 변형별로 다르게 하고(`pen_holder_<folder>`) 저장 후 `closeDocument`한다 — 한 프로세스에서 4개를 연속 만들면 같은 이름이 충돌한다.

## 막혔던 곳 / 학습
1. **봉인 스크립트가 브랜치 루트를 요구해 처음에 거부됐다**(exit 2, `EMPTY no-forge-state`). 현재 브랜치가 `feature/filament-saving`인데 forge 상태를 최상위 `.forge/`에 써 왔기 때문이다(ADR-0011은 비default 브랜치에서 `.forge/branch/<브랜치>/`를 요구). 이 브랜치에서 만든 작업(#3 활성 슬롯, #4 백로그)만 브랜치 루트로 옮겨 해결했고, main에서 봉인된 `done/`·`retro/`·`CONTEXT.md`·`adr/`는 그대로 두었다 — 그건 main의 이력이다.
2. 브랜치 전환을 **세션 중간에 인지하지 못하면 상태가 엉뚱한 곳에 쌓인다.** 작업 시작 시 브랜치를 확인하는 습관이 필요하다.

## 다음 단계 (검증 범위 외)
- 이 브랜치를 main에 합칠 때 `.forge/branch/feature/filament-saving/`의 이력을 최상위로 옮길지 결정해야 한다(fg-merge가 그 통합을 담당한다).
- 릴리스 `1.0`은 여전히 main의 벽 3.0mm 시절 형상을 가리킨다. 4변형 구조를 릴리스에 반영하려면 자산명을 `w70-wall2.4-tier1.stl` 식으로 접두어를 붙여 재업로드해야 한다.

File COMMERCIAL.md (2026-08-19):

# 상업 이용 안내 / Commercial Use

이 프로젝트는 **이중 라이센스**입니다. 비상업적 이용은 무상이고, 상업적
이용에는 저작권자로부터 별도 라이센스를 취득해야 합니다.

This project is **dual-licensed**: free for noncommercial use, and commercial
use requires a separate license from the copyright holder.

| 대상 | 비상업 이용 | 상업 이용 |
|---|---|---|
| 소스 코드 (`pen_holder.py`, `screenshot.py`) | PolyForm Noncommercial 1.0.0 — 무상 | 별도 라이센스 필요 |
| 도면·모델 (`output/`, `output-8cm/`) | CC BY-NC-SA 4.0 — 무상 | 별도 라이센스 필요 |

## 별도 라이센스 없이 자유롭게 할 수 있는 것

- 개인·가정에서 쓰려고 **출력하는 것** (몇 개를 뽑든 상관없습니다)
- 친구·가족에게 뽑아 **무상으로 주는 것**
- 학교, 도서관, 메이커스페이스, 동아리 등 **교육·비영리 목적의 출력과 사용**
- 모델이나 스크립트를 **수정하고, 그 결과를 비상업적으로 재배포하는 것**
  (출처 표시 + 동일한 조건으로 공개)
- 회사 사무실에서 **자기 책상에 쓰려고 하나 뽑아 쓰는 것**

## 별도 라이센스가 필요한 것

- 출력물을 **판매**하는 것 (온라인 마켓, 오프라인, 소량 여부 무관)
- **유료 서비스·유료 제품의 일부**로 제공하는 것
- 이 설계를 이용한 **상업적 주문 제작·수탁 생산**
- 상업적 제품의 **금형·양산 원형**으로 쓰는 것
- 유료 강의·유료 콘텐츠의 **판매 상품**으로 배포하는 것

경계가 애매하면 문의해 주세요. 묻는 것 자체는 무료이고, 대부분의 개인적
사용은 별도 라이센스 없이 가능합니다.

## 문의 방법

저장소에 이슈를 남겨 주세요:

    https://github.com/gyuha/fixed-angled-drawer/issues

문의할 때 아래를 적어 주시면 회신이 빠릅니다.

- 어떤 용도로 쓰려는지 (판매/서비스/양산 등)
- 예상 수량 또는 규모
- 연락처

## 참고

- 라이센스 변경 시점(2026-08-19) **이전**에 배포된 버전은 그 시점의
  라이센스(MIT / CC BY-SA 4.0)로 받은 사람에게 계속 유효합니다. 라이센스
  변경은 이후 버전에만 적용됩니다.
- 저작권자는 자신의 저작물을 자유롭게 이용·재라이센스할 수 있습니다.

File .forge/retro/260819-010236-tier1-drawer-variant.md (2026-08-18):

# 2026-08-19 — 1단 서랍 변형(tier1-drawer)과 서랍 부품

## 계획 대비 실제
- 계획대로 된 것: 기존 tier1을 건드리지 않고 인자 분기(`make_tier1(drawer=True)`)만으로 변형을 얻었다. 파라메트릭 구조 덕에 쐐기 전환·레일 역할 교체·레일 구간 축소가 모두 파라미터와 함수 수정으로 끝났고, 검증 31항목이 매번 회귀를 잡아 줬다.
- 어긋난 것: **한 번 재실행했다.** 1차는 계획대로 사각 서랍을 만들었으나, 실물 렌더를 본 뒤 "경사 공간도 쓰고 싶다"로 요구가 바뀌어 쐐기형으로 다시 만들었다. 이어서 레일 역할 교체(홈=서랍)·레일 4/5 구간·개구 모서리 라운딩이 순차로 추가됐다. 목표 자체가 흔들린 게 아니라 형태 선택이 실물을 보고 뒤집힌 경우다.

## 학습
- 다음에 다르게 할 것:
  1. **형태 선택은 텍스트 스케치가 아니라 렌더로 물어라.** 그릴링에서 사각 vs 쐐기를 ASCII 단면으로 비교해 사각을 골랐는데, 실제 렌더를 보자마자 쐐기로 뒤집혔다. 이 프로젝트에는 이미 `screenshot.py`가 있으니, 형태가 갈리는 결정은 두 안을 렌더해 보여 주고 고르게 하면 재실행 한 번을 아낀다. (시각 컴패니언 `fg-visual`도 같은 목적으로 쓸 수 있다.)
  2. **형상이 바뀌면 "중앙"의 의미가 바뀐다.** 사각 서랍에서는 기하 중앙 = 무게중심이었지만 쐐기에서는 43.8mm vs 29.0mm로 **14.8mm** 벌어진다. 손가락 개구를 "앞판 중앙"이라는 상수로 박아 뒀다면 "무게중심에서 당겨 모멘트 0"이라는 합의가 조용히 깨졌을 것이다. 치수는 상수로 박지 말고 `CenterOfMass`처럼 **솔리드에서 유도**되게 두면 형상 변경을 자동으로 따라온다.
  3. **검증 코드 자체도 검증이 필요하다.** 앞판 개구를 확인하려고 짠 첫 쿼리가 앞판 전체 정점을 잡아 "개구 폭 58.2mm"라는 무의미한 값을 냈다. 판정식(타원 방정식)으로 좁혀 다시 짜야 했다. 검증이 PASS라고 해서 검증이 옳은 것은 아니다.
  4. **감각으로 갈리는 논쟁은 수치로 끝난다.** 손잡이 vs 손가락 구멍은 취향 문제처럼 보였지만, 필요 당김력을 계산하니(400g·μ0.4 → 1.6N, 뻑뻑해도 5N) 손잡이의 그립력 이점이 이 제품에서는 쓸 데가 없다는 게 분명해졌다. 대신 실제로 아픈 지점(개구 모서리)만 라운딩으로 해결했다.
- FreeCAD 함정 하나 추가: **`Part.Compound`에는 `CenterOfMass`가 없다.** 불리언 결과가 컴파운드로 감싸져 나오므로 `shape.Solids[0].CenterOfMass`로 접근해야 한다. (지난 회고의 `removeSplitter`·`common()`·`BoundBox`·`exportStl` 함정과 같은 부류 — FreeCAD는 연산에 따라 형상 타입이 바뀐다는 점을 매번 의식해야 한다.)

## 문서 갱신
- CONTEXT.md 승급: 서랍 구간·서랍 정의를 쐐기형·전체 높이 앞판·무게중심 개구로 정정, **레일(guide rail)** 신규 등재(홈=서랍/리브=본체, 깊이의 4/5 구간)
- ADR 추가: 없음 (형태 선택·레일 방식 모두 파라미터·형상 수정으로 되돌릴 수 있어 기준 미달)

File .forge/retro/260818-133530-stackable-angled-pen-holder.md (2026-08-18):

# 2026-08-18 — 적층형 경사 필통 FreeCAD 파라메트릭 모델

## 계획 대비 실제
- 계획대로 된 것: 부품 3종을 파라메트릭 스크립트 하나로 생성하고 헤드리스 검증까지 통과. 외형 치수·경사각·나사 규격·스냅 공차 모두 합의값과 일치. 모든 치수가 스크립트 상단 상수로 노출되어, 이후 폭 80→70mm·칸 수 변형·마감 모듈 추가가 전부 파라미터/함수 인자 수정만으로 처리됨.
- 어긋난 것: 5개 조각 중 4개가 FreeCAD/OCC의 API 함정으로 우회 설계를 요구했다(아래 학습). 형상 목표 자체는 어긋나지 않았고, 전부 구현 수단의 문제였다. 계획에 없던 판단 3건: 전 칸 앞턱 통일, 상단 라운드 생략, 스냅 돌기를 발자국 안쪽으로.

## 학습
- 다음에 다르게 할 것:
  1. **헬리컬(나사산) 솔리드에는 OCC 정리 연산을 걸지 말 것.** `removeSplitter()`는 유효한 솔리드를 invalid로 만들고, `common()` 클리핑은 *조용히 실패*해 잘리지 않은 형상을 반환한다. 나사산 끝단은 잘라내지 말고 다른 재료 속에 묻히도록 배치하는 편이 안전하다.
  2. **치수 검증에 `Shape.BoundBox`를 쓰지 말 것.** 트림 전 곡면 제어점 기준이라 헬리컬 절삭 후 실제보다 2.6mm 크게 나온다. `tessellate()` 기반 실측 bbox를 쓸 것.
  3. **STL은 `MeshPart.meshFromShape` + `mesh.write()`로 내보낼 것.** `Shape.exportStl()`은 ASCII를 써서 헬리컬 부품이 8.6MB → 138KB 차이가 난다.
  4. **기능이 성립하는지를 검증 항목으로 만들 것.** 이 작업의 검증 9항목은 "유효 솔리드·치수 일치"만 봤고, 그래서 *나사가 아래턱 위로 10mm만 올라와 두께 30mm 미만 상판에는 닿지 않는다*는 결함을 놓쳤다(사용자가 실제 출력 후 발견). 이후 '체결 가능 상판 두께'·'구멍 주변 재료'·'앞턱 자기지지 각도'처럼 **기능 성립 조건을 계산해 판정하는 항목**을 넣자 같은 종류의 결함이 즉시 걸렸다. 치수 검증은 "그린 대로 그려졌나"만 답하고 "쓸 수 있나"는 답하지 않는다.
  5. **출력 방향을 설계 초기에 정하고 그 방향 기준으로 형상을 판단할 것.** 서포트 면적을 광선 투사로 실측해 보니 방향에 따라 3,700 vs 28,800mm²로 8배 차이였고, 앞턱의 수직 단차 같은 결함은 "뒷면을 베드에"라는 전제를 세운 뒤에야 보였다.
- 문서 신선도: 퀵 레인(fg-quick) 작업이 연달아 형상을 바꾸면서 CONTEXT.md 용어 정의가 실제와 어긋났다(칸 수·부품 구성). 퀵 레인은 설계상 문서를 갱신하지 않으므로, 퀵 작업이 여러 건 누적되면 회고 때 용어집을 한 번 대조하는 편이 좋다.

## 문서 갱신
- CONTEXT.md 승급: 경사 칸(칸 수 고정 기술 → 부품별 가변), 적층 모듈·1단(폭·칸 수·바닥 개방), 클램프·썸스크류(체결 범위) 정의 갱신 + 마감 모듈·평판 뚜껑·앞턱 신규 등재
- ADR 추가: 없음 (FreeCAD API 함정 4건은 되돌리기 어려운 결정도, 트레이드오프도 아니라 기준 미달)

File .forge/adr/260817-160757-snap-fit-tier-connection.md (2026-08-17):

---
id: 260817-160757
author: gyuha
decided: 2026-08-17 16:07
---
# 단간 연결 방식으로 스냅핏 클립 채택 (도브테일 대신)

## 맥락
적층형 경사 필통은 모듈을 계속 쌓아 올리는 구조라, 단 사이 연결 인터페이스는 모든 모듈이 공유한다. 한 번 프린트한 뒤 인터페이스를 바꾸면 기존 모듈 전부를 재출력해야 하므로 되돌리기 비용이 크다. 후보는 립&리세스(얹기), 도브테일 슬라이드, 스냅핏 클립이었고, "높이 올려도 흔들리지 않게"라는 요구 기준으로 시각 컴패니언 단면도 비교를 거쳤다.

## 결정
스냅핏 클립을 채택한다 — 위 모듈 바닥의 일체형 후크가 아래 모듈 상단 캐치 구멍에 눌러 끼워져 고정된다. 에이전트 권장안은 도브테일 슬라이드(수직·수평 모두 잠기고 마모 없음)였으나, 사용자가 조립 편의(위에서 눌러 딸깍)를 우선해 스냅핏을 선택했다.

## 트레이드오프
- 얻는 것: 위에서 눌러 끼우는 직관적 조립, 수직 방향 잠금(들어도 안 빠짐), 슬라이드 공간 불필요.
- 감수하는 것: 반복 분해 시 후크 마모·파손 위험, 후크가 프린트 방향(레이어 접착)에 민감함. 완화책으로 후크를 본체 일체형으로 두껍게 설계하고 공차를 파라미터화한다.

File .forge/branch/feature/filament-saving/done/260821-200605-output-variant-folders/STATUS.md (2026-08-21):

# STATUS — 4개 변형(폭 × 두께)을 폴더별로 생성
slug: output-variant-folders
status: done
executed: 2026-08-21
completed: 2026-08-21
verified: yes (freecadcmd pen_holder.py → 변형당 33항목 × 4변형 = 132개 PASS·FAIL 0, 변형별 세트 재료 511/548/601/646cm³로 서로 다름 실측, 3mf 2개 대응 폴더 이관·output-8cm 폐지·README 이미지 링크 무결 확인)
retro: skipped (fg-next all 자동 드라이브 — 학습은 run.md에 남고 승급은 이후 fg-learn으로 미룸)
docs updated: README 변형 선택 절·파일 구조·검증 개수 표기 제거

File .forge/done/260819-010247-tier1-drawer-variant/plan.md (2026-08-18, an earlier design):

<!-- forge-slug: tier1-drawer-variant -->
<!-- task: 2 -->
<!-- tdd: off -->
# 1단 서랍 변형(tier1-drawer)과 서랍 부품 추가

## 목표 / 비목표
- 목표: 기존 `tier1`을 그대로 남긴 채, 최하단 칸을 사각 서랍 구간으로 바꾼 변형 `tier1-drawer`와 그 안에 끼우는 별도 부품 `drawer`를 생성한다. 두 부품 모두 STL로 내보내고, 서랍이 실제로 들어가고 빠지는지를 검증 항목으로 판정한다.
- 비목표: 기존 tier1 형상 변경, module2·module3·topmodule·lid·thumbscrew 변경, 슬라이드 레일·스토퍼·손잡이 별도 부품, 서랍 내부 칸막이, 서랍이 빠지지 않게 막는 장치(뒷부분 이탈 방지 툴은 "당기면 완전히 빠진다"는 결정과 상충하므로 넣지 않음).

## 확정 사양 (그릴링 합의)
- **대상 칸**: tier1의 **최하단 칸 1개**(경사 선반 + 그 아래 포켓)를 통째로 서랍 구간으로 대체. 위 2칸은 기존 경사 칸 그대로. 외형·클램프·상단 캐치·스냅 인터페이스는 tier1과 동일.
- **서랍 형태**: **쐐기 서랍** — 경사 천장을 따라가 앞이 높고(87.5mm) 뒤가 낮다(52.9mm). 천장과 서랍 상면의 기울기가 같아 인출·삽입 중 간섭이 없다(빼면 여유가 오히려 늘어난다). 별도 천장판은 두지 않는다 — 경사 공간을 서랍이 직접 쓴다. 내부 용적 약 350cm³ (사각안 대비 +30%).
- **앞판**: **플러시 인셋 + 개구 전체 높이 커버**. 앞판이 바닥부터 천장까지(z 4~91.5) 개구를 덮어 안쪽을 최대로 쓴다. 밀어 넣으면 뒷벽 2mm 앞에서 멈추고, 당기면 완전히 빠진다.
- **손가락 개구**: 앞판의 **가로 타원 관통구 30×16mm**, 위치는 **빈 서랍의 실제 무게중심 높이**(솔리드에서 계산, 현재 z=29.0). 당김점·무게중심·레일이 한 선에 놓여 기울임 모멘트가 0이 된다. 형상이 바뀌면 자동으로 따라온다. **개구 모서리는 앞뒤 양면 r1.0으로 굴린다** — 3mm 판을 그냥 뚫으면 손가락이 걸리는 각진 모서리가 살을 파고든다. (돌출 손잡이는 채택하지 않음: 필요 당김력이 1.6~5N에 불과해 그립력 이점이 없고, 앞으로 튀어나온 형상은 바닥 안착 출력에서 오버행이 되어 서포트 0을 깨며, 전 부품 플러시 디자인과 어긋난다.)
- **가드 레일**: **홈은 서랍 측벽, 리브는 본체 측벽**(서랍이 파이는 쪽). 홈 1.4깊이 × 3.0높이 / 리브 1.0돌출 × 2.4높이 → 상하 각 0.30 · 깊이 0.40mm 여유. **레일은 앞면까지 나오지 않는다** — 깊이의 앞 1/5(19mm)을 비우고 **4/5 구간만** 안내한다(`RAIL_START=0.2`). 76mm까지 안내되다가 그 이상 빼면 리브가 홈 뒤끝으로 빠져 분리된다. 홈 뒤 서랍 벽은 안쪽 보강 패드로 두께를 2.1mm로 회복한다.
- **타공**: 서랍 자체는 전면 타공 없음. **본체도 서랍 구간에서는 타공 제외**(서랍이 닿는 면이라 걸림·먼지 방지). 위 2칸 구간의 타공은 유지.
- **공차 (파라미터)**: 서랍 좌우 각 0.4mm, 상하 합 0.5mm, 깊이 뒷벽 앞 2mm 여유. **레일 공차 `RAIL_CLEAR` — 상하 각 0.3mm·깊이 0.4mm.** 서랍 벽 2.5mm·바닥 3mm·앞판 3mm 권장. 레일은 공차에 민감해 첫 출력에서 빡빡하거나 헐거우면 이 값을 조정해 재출력한다.
- **출력 방향**: 본체는 기존과 동일하게 뒷면을 베드에. 서랍은 바닥을 베드에(위가 열려 서포트 불필요).
- **회고 반영**(`.forge/retro/260818-133530-*`): 치수 검증만으로는 "쓸 수 있는지"를 못 잡는다 → 아래 DoD에 **끼움·공차·홈 크기**를 계산 판정 항목으로 넣는다. 헬리컬 솔리드가 아니므로 OCC 필렛·불리언 제약은 이번 작업엔 해당 없음.

## 진실의 원천
- 용어: `.forge/CONTEXT.md`의 서랍 구간 · 서랍 · 1단 · 경사 칸 · 앞턱
- 관련 ADR: 없음 (되돌리기 어려운 결정 없음 — 형태 선택은 파라미터/형상 수정으로 되돌릴 수 있음)
- 완료 정의(DoD): `freecadcmd pen_holder.py` 실행 시 `output/tier1-drawer.stl`·`output/drawer.stl`이 생성되고, 검증에서 (a) 두 부품 모두 유효 솔리드, (b) 서랍이 구간에 좌우 각 0.4·상하 0.5mm 여유로 들어가고 쐐기 기울기가 천장과 일치, (c) 밀어 넣으면 뒷벽 앞에서 멈춤, (d) 손가락 개구 30×16mm이고 중심이 빈 서랍 무게중심 높이, (e) 서랍 구간 본체 측벽과 서랍의 타공 수가 0, (f) 레일 끼움(상하 각 0.3·깊이 0.4mm 여유, 홈 뒤 벽 ≥1.5mm)과 레일 구간(앞면 노출 없음, 깊이의 4/5 안내) — 이 항목들이 모두 PASS로 출력된다.

## 작업 조각
- [ ] S1. `tier1-drawer` 본체 — 최하단 칸의 경사 선반·앞턱·하단 포켓을 제거해 바닥~경사 천장을 통째로 서랍 구간으로 열고, 측벽에 레일 리브를 붙이고 구간 타공 제외. 위 2칸·클램프·상단 캐치는 tier1과 동일 — 완료 기준: 유효 솔리드이고 서랍 구간이 바닥~경사 천장까지 열려 있으며, 양 측벽 리브가 앞에서 19mm 들어간 지점부터 있고 그 구간 타공 수 0
- [ ] S2. `drawer` 부품 — 쐐기 상자(위 개방·타공 없음) + 전체 높이 앞판 + 무게중심 높이의 타원 개구 + 양 측벽 레일 홈(앞 1/5 비움) + 홈 보강 패드 — 완료 기준: 유효 솔리드, 개구 30×16mm이고 중심이 무게중심 높이, 홈이 본체 리브와 공차 내로 물림 (depends: S1)
- [ ] S3. 끼움 검증 항목 추가(서랍 공차·레일 공차·깊이 정지·타공 0) + FCStd 배치(부품 나열 + 서랍을 빼낸 분해 뷰) + STL 2개 내보내기 — 완료 기준: DoD 다섯 항목 전부 PASS 출력, 스크린샷 재생성 (depends: S1, S2)

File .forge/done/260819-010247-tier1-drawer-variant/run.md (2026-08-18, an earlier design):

<!-- forge-slug: tier1-drawer-variant -->
# 실행 기록 — 1단 서랍 변형(tier1-drawer)과 서랍 부품 추가

> 1차 실행(사각 서랍) 후 요구가 바뀌어 계획을 갱신하고 **재실행**한 기록이다.
> 변경 3건: 쐐기 서랍으로 경사 공간 사용 · 레일 역할 교체(홈=서랍) · 레일을 앞면까지 내지 않고 깊이의 4/5만.

## 조각별 결과
- S1 `tier1-drawer` 본체 (바닥~경사 천장 통째 개방 + 측벽 리브 + 구간 타공 제외) — ✅ 계획대로
- S2 `drawer` 부품 (쐐기 상자 + 전체 높이 앞판 + 무게중심 높이 타원 개구 + 개구 모서리 r1.0 + 홈·보강 패드) — ✅ 계획대로
- S3 검증 항목 확장 + FCStd 배치 + STL 내보내기 — ⚠ `Part.Compound`에 `CenterOfMass`가 없어 `Solids[0]`에서 구해야 했음

## 계획대로 된 것
- 기존 `tier1`은 여전히 형상 변화 없음(변형은 `make_tier1(drawer=True)` 인자 분기). 부품 8종 모두 유효 솔리드, 검증 30항목 PASS.
- 쐐기 서랍: 63.2 × 95mm, 앞 높이 **87.5mm** → 뒤 **52.9mm**. STL 실측으로 상면 기울기가 천장과 동일함을 확인(y=0에서 87.5, y=95에서 52.9). 기울기가 같아 인출·삽입 중 간섭이 없고, 빼낼수록 여유가 늘어난다.
- 앞판이 개구 전체(z 4~91.5)를 덮어 안쪽을 최대로 쓴다. 내부 용적 약 **350cm³** (사각안 대비 +30% 남짓).
- 레일 역할 교체 확인: 서랍 측벽에 홈(module z 31.5~34.5), 본체 측벽에 리브(31.78~34.18) → 리브가 홈 안에 아래 0.28 · 위 0.32mm 여유로 물린다.
- 레일 구간: 홈·리브 **모두 y=19mm(깊이의 1/5)부터** 시작해 앞면에 드러나지 않는다(STL 실측). 깊이의 4/5가 안내되어 **76mm 인출까지 처짐 없이** 지지되고, 그 이상 빼면 리브가 홈 뒤끝으로 빠져 분리된다.
- 타공: 서랍 구간(경사 천장 아래) 본체 0개 · 서랍 0개.

## 현장 결정 (계획에 없던 판단)
- **손가락 개구 높이를 고정값이 아니라 솔리드의 무게중심에서 계산**하도록 바꿨다. 쐐기 형상은 기하 중앙(43.8mm)과 무게중심(29.0mm)이 크게 다르므로, 중앙에 두면 애초의 의도(무게중심에서 당겨 모멘트 0)가 깨진다. `CenterOfMass`로 구해 개구와 레일을 같은 높이에 두었고, 형상이 바뀌면 자동으로 따라온다.
- 천장판 파라미터(`DRAWER_CEIL_T`)를 삭제했다 — 쐐기 서랍이 경사 공간을 직접 쓰므로 천장판이 오히려 공간을 막는다.
- 타공 회피를 "특정 높이 아래 제외"에서 **"경사 천장 아래 전체 제외"(구멍별 판정)** 로 바꿨다. 서랍 구간이 이제 경사면이라 단순 높이 기준으로는 맞지 않는다.
- 홈을 판 뒤 서랍 벽이 1.1mm로 얇아지므로, 홈 뒤쪽에만 안쪽 보강 패드(1.0mm)를 덧대 2.1mm를 회복했다. 내부 용적 손실은 3mm 띠뿐이다.

- **손잡이 대신 구멍을 유지하고 모서리만 굴렸다.** 돌출 손잡이를 검토했으나 (1) 필요 당김력이 400g 기준 1.6N, 뻑뻑해도 5N 수준이라 손가락 하나로 충분하고 (2) 앞으로 돌출한 형상은 바닥 안착 출력에서 오버행이 되어 이 프로젝트의 서포트 0을 깨며 (3) 전 부품 플러시 디자인과 어긋나 채택하지 않았다. 대신 실제로 힘이 걸리는 개구 모서리를 앞뒤 양면 r1.0으로 굴려 손가락 압박만 덜었다(STL에서 곡면 확인).

## 막혔던 곳 / 학습
1. **`Part.Compound`에는 `CenterOfMass`가 없다.** 불리언 결과가 컴파운드로 감싸져 나오므로 `shape.Solids[0].CenterOfMass`로 접근해야 한다. FreeCAD의 형상 타입이 연산에 따라 바뀐다는 점을 매번 의식해야 한다.
2. **형상을 바꾸면 "중앙"의 의미가 바뀐다.** 사각 서랍에서는 기하 중앙 = 무게중심이었지만 쐐기에서는 14mm 차이가 난다. 치수를 상수로 박아두면 이런 변경에서 조용히 의도를 잃는다 — 계산으로 유도되게 두는 편이 안전하다.

## 다음 단계 (검증 범위 외)
- 실제 출력에서 서랍 미끄러짐은 프린터 공차에 달렸다. 빡빡하면 `RAIL_GROOVE_H`/`RAIL_GROOVE_D`를 키우거나 `DRAWER_CLEAR`를 0.5로, 헐거우면 반대로 조정해 서랍만 재출력하면 된다.
- 출력 방향: 본체는 뒷면을 베드에, 서랍은 바닥을 베드에(위 개방·상면 경사 모두 서포트 불필요).

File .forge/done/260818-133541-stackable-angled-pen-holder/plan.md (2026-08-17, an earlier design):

<!-- forge-slug: stackable-angled-pen-holder -->
<!-- task: 1 -->
<!-- tdd: off -->
# 적층형 경사 필통 FreeCAD 모델링

## 목표 / 비목표
- 목표: 파라메트릭 FreeCAD Python 스크립트 하나로 3개 부품(1단 클램프형 필통, 적층 모듈, 썸스크류)을 생성하고 FCStd + 부품별 STL로 내보낸다. 모든 치수는 스크립트 상단 파라미터로 조정 가능해야 한다.
- 비목표: 슬라이싱/프린트 프로파일, 조립 설명서, 도브테일 등 다른 연결 방식 변형, 3칸 변형 모델, 업로드된 참고 클램프 부품의 재현.

## 확정 사양 (그릴링 합의)
- **모듈 외형**: 폭 80 × 깊이 100 × 높이 170mm (후크·클램프 돌출 제외). 경사 칸 2개, 칸 피치 85mm.
- **경사각**: 수평 대비 20° — 참고 STL(`reference/pen-holder-reference.stl`) 법선 실측값.
- **단간 연결**: 스냅핏 클립 — 위 모듈 바닥의 후크가 아래 모듈 상단의 캐치 구멍에 딸깍 고정. 모든 모듈(1단 포함)의 상단 캐치는 동일 형상 → 어느 모듈이든 최상단이 될 수 있고 같은 모듈을 무한 적층. 반복 분해 마모를 고려해 후크는 본체 일체형으로 두껍게. 결정 근거: `.forge/adr/260817-160757-snap-fit-tier-connection.md`
- **1단 고정**: 뒷면 일체형 ㄷ자 책상 모서리 클램프. 개구(상판 물림) 40mm — 상판 18~25mm + 조임 여유. 아래턱에 암나사.
- **나사 규격** (업로드 썸스크류 실측, 호환 유지): 외경 18.5mm / 골지름 12.7mm / 피치 4mm / 나사부 길이 22mm / 손잡이 Ø32.6×10mm. 새 썸스크류도 이 규격으로 모델링 — 사용자의 기존 나사(`reference/thumbscrew-reference.stl`)를 그대로 끼울 수 있어야 한다.
- **공차 (파라미터 기본값)**: 스냅핏 0.25mm, 암나사 반경 방향 0.4~0.5mm.
- **벽 두께 등 세부 형상**: 참고 STL에서 실측해 채택 (S1에서 확정).
- **검증 환경**: `/Applications/FreeCAD.app` 설치 확인됨 — headless 실행으로 검증.

## 진실의 원천
- 용어: `.forge/CONTEXT.md`의 적층 모듈 · 1단 · 스냅핏 클립 · 경사 칸 · 클램프 · 썸스크류
- 관련 ADR: `.forge/adr/260817-160757-snap-fit-tier-connection.md`
- 완료 정의(DoD): 저장소에 파라메트릭 스크립트 + FCStd + STL 3개(`tier1.stl`, `module.stl`, `thumbscrew.stl`)가 생성되고, headless 검증이 (a) 3개 부품 모두 유효 솔리드, (b) 모듈 바운딩박스 80×100×170mm(돌출 제외) 일치, (c) 나사-암나사 치수 정합(공차 포함)을 통과 출력한다.

## 작업 조각
- [ ] S1. 참고 STL 실측 상세화 — 벽 두께, 앞벽(입술) 높이, 바닥 두께, 상단 라운드 반경을 `reference/pen-holder-reference.stl`에서 측정해 파라미터 표 확정 — 완료 기준: 스크립트 상단 PARAMS에 실측 근거 주석과 함께 기록됨
- [ ] S2. 적층 모듈 모델링 — 경사 2칸(20°) 본체 + 상단 캐치 + 바닥 스냅 후크 — 완료 기준: headless 실행 시 유효 솔리드, 외형 80×100×170mm(후크 제외) (depends: S1)
- [ ] S3. 1단 모델링 — 모듈 본체(상단 캐치 동일) + 뒷면 ㄷ자 클램프(개구 40mm) + 아래턱 암나사(피치 4mm) — 완료 기준: 유효 솔리드, 암나사 내경·피치가 나사 규격+공차와 일치 (depends: S2)
- [ ] S4. 썸스크류 모델링 — 완료 기준: 외경 18.5 / 피치 4 / 나사부 22mm ±0.1, 유효 솔리드 (depends: S1)
- [ ] S5. FCStd 저장 + STL 3개 내보내기 + 검증 리포트 — 완료 기준: DoD의 headless 검증 3항목 통과 출력 (depends: S2, S3, S4)

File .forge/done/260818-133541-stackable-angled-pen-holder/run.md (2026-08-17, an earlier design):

<!-- forge-slug: stackable-angled-pen-holder -->
# 실행 기록 — 적층형 경사 필통 FreeCAD 모델링

## 조각별 결과
- S1 참고 STL 실측 (벽 3mm·바닥/선반 4mm·경사 20°·앞면 밴드+립 구조·선반 아래 중공 쐐기) — ✅ 계획대로
- S2 적층 모듈 모델링 — ⚠ 참고 모델의 상단 라운드(필렛)는 스냅 인터페이스 단순화를 위해 생략
- S3 1단(클램프+암나사) 모델링 — ⚠ 검증 방법 교체 (OCC BoundBox 과대추정 → 테셀레이션 실측)
- S4 썸스크류 모델링 — ⚠ 나사산 클리핑 우회 (common() 실패 → 끝단을 재료 속에 묻는 배치)
- S5 FCStd + 바이너리 STL 3개 내보내기, 검증 9항목 PASS — ⚠ exportStl이 ASCII로 출력되어 MeshPart 바이너리 내보내기로 교체

## 계획대로 된 것
- 3개 부품(module / tier1 / thumbscrew) 모두 유효 솔리드로 생성, 외형 치수 요구 사양과 일치 (module 80×100×170 + 스커트 12, tier1 개구 40mm, 나사 OD 18.5·피치 4·나사부 22).
- 단면 시각 점검으로 형상 확인: 선반 앞-높음/뒤-낮음 20° 경사, 앞턱, 중공 쐐기, ㄷ자 클램프, 암나사 홈 모두 의도대로.
- 파라메트릭: 모든 치수가 스크립트 상단 PARAMS 상수(실측 근거 주석 포함)로 노출됨.

## 현장 결정 (계획에 없던 판단)
- 모든 칸에 앞턱(립) 6mm 통일 적용 — 참고 모델은 최하단만 밴드였으나, 물건 미끄럼 방지 목적의 기능 개선. 파라미터 `LIP`로 조정 가능.
- 상단 라운드(필렛) 생략 — 참고 모델의 곡면 마감은 미관용이고, 스냅 캐치 창이 있는 상단 테두리를 평면으로 유지하는 편이 결합 강성과 불리언 안정성에 유리.
- 스냅 돌기는 모듈 발자국(80mm) 안쪽으로 돌출하도록 설계 — 외형 치수가 커지지 않음.

## 막혔던 곳 / 학습
1. **`removeSplitter()`가 헬리컬 스윕이 포함된 솔리드를 invalid로 만든다** (FreeCAD 1.1.3). 미관용 호출이라 전부 제거로 해결.
2. **`Shape.common()` 클리핑이 헬리컬 파이프셸 솔리드에 조용히 실패한다** — 결과가 잘리지 않은 채 반환됨. 나사산 양 끝의 프로파일 돌출(±1.4~1.6mm)을 손잡이·턱 재료 속에 묻는 배치로 우회.
3. **OCC `BoundBox`는 트림 전 곡면 제어점 기준의 과대 추정** — 헬리컬 절삭 후 bbox가 실제보다 2.6mm 크게 나옴. 치수 검증은 `tessellate()` 기반 실측 bbox(`TightBB`)로 해야 정확.
4. **`Shape.exportStl()`은 ASCII STL을 쓴다** — 헬리컬 부품이 8.6MB로 비대. `MeshPart.meshFromShape` + `mesh.write()`로 바이너리 출력 (138KB).

## 프린트 참고 (검증 범위 외 권고)
- module: 뒷면을 베드에 대고 출력 권장 (경사 선반이 70° 벽이 되어 서포트 최소화).
- tier1: 클램프 뒷판 때문에 뒷면 안착 불가 — 앞면을 베드에 대는 방향 권장.
- 스냅 공차(CLEAR=0.25)·나사 공차(THR_CLEAR=0.4)는 프린터에 따라 첫 시험 인쇄 후 조정.

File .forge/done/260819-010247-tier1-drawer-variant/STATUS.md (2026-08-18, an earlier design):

# STATUS — 1단 서랍 변형(tier1-drawer)과 서랍 부품 추가
slug: tier1-drawer-variant
status: done
executed: 2026-08-19
completed: 2026-08-19
verified: yes (freecadcmd pen_holder.py → 검증 31항목 PASS + STL 실측: 쐐기 앞87.5→뒤52.9 기울기 천장과 일치, 홈 31.5~34.5에 리브 31.78~34.18 물림, 홈·리브 y=19부터(앞면 노출 0), 서랍 구간 타공 0, 개구 모서리 r1.0 곡면)
retro: /Users/gyuha/workspace/fixed-angled-drawer/.forge/retro/260819-010236-tier1-drawer-variant.md
docs updated: CONTEXT.md 서랍 구간·서랍 정정 + 레일 신규 등재

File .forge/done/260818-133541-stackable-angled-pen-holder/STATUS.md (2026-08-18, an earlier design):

# STATUS — 적층형 경사 필통 FreeCAD 모델링
slug: stackable-angled-pen-holder
status: done
executed: 2026-08-17
completed: 2026-08-18
verified: yes (freecadcmd pen_holder.py → 검증 9항목 PASS: 유효 솔리드 3종·바운딩박스·나사/스냅 정합)
retro: /Users/gyuha/workspace/fixed-angled-drawer/.forge/retro/260818-133530-stackable-angled-pen-holder.md
docs updated: CONTEXT.md 용어 9개(마감 모듈·평판 뚜껑·앞턱 신규 포함)

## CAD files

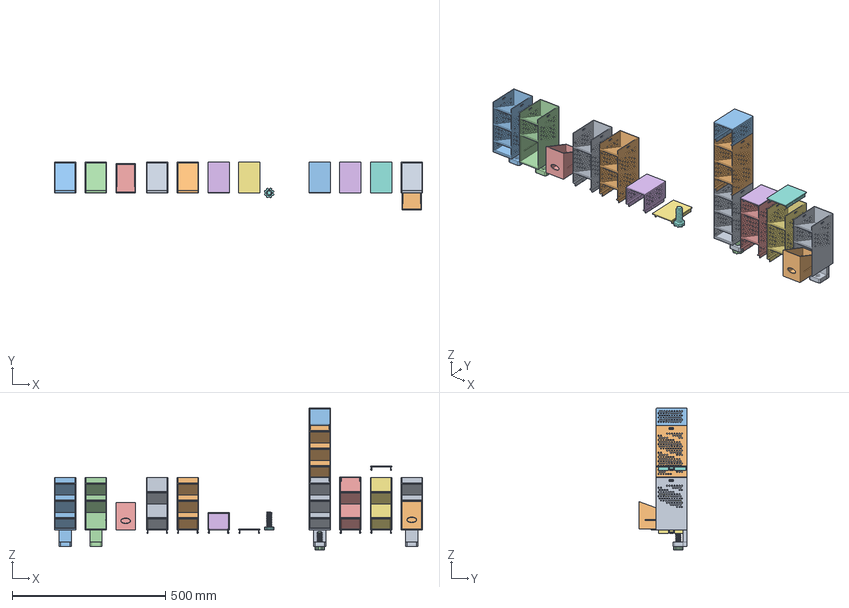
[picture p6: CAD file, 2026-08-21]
output/w70-wall2.4/pen_holder.FCStd
1200.0 x 155.0 x 461.7 mm
module2
module3
tier1
tier1_drawer
drawer
topmodule
lid
thumbscrew
asm_tier1
asm_module3
asm_topmodule
asm_screw
asm_module2
asm_lid
exp_module2
exp_lid
exp_tier1d
exp_drawer

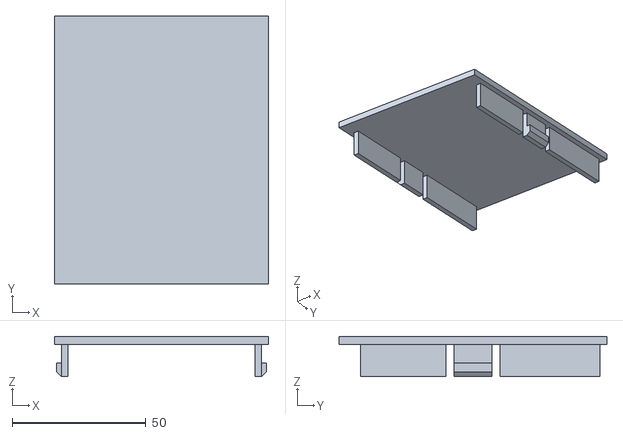
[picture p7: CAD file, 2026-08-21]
output/w80-wall2.4/lid.stl
80.0 x 100.0 x 15.0

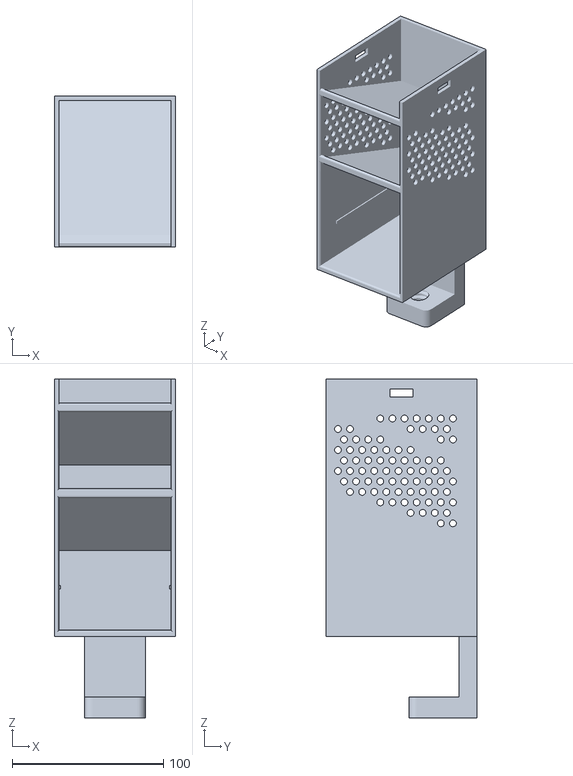
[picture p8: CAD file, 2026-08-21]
output/w80-wall3.0/tier1-drawer.stl
80.0 x 100.0 x 224.0

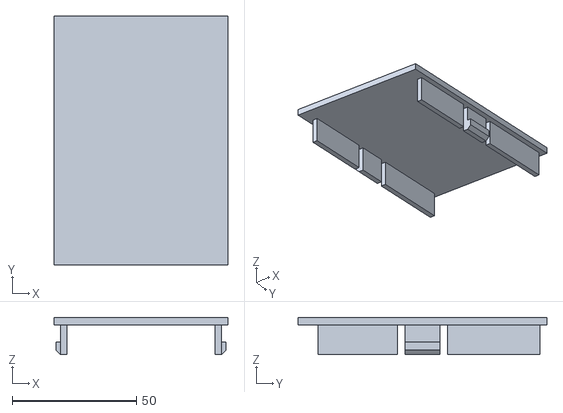
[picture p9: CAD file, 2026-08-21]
output/w70-wall2.4/lid.stl
70.0 x 100.0 x 15.0

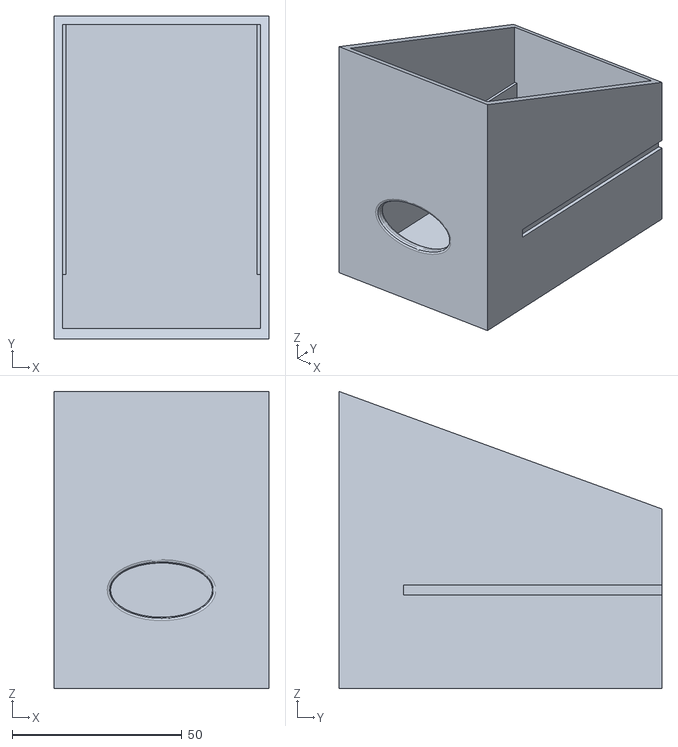
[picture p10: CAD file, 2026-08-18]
output/w70-wall3.0/drawer.stl
63.2 x 95.0 x 87.5

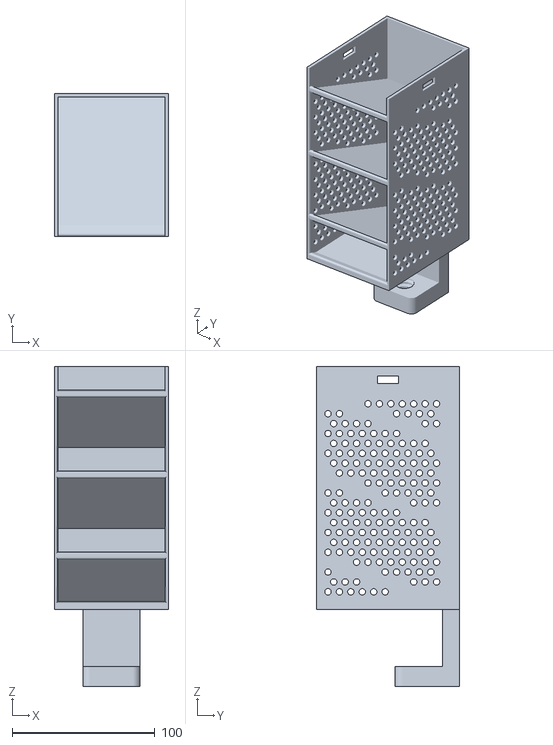
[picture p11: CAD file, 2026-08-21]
output/w80-wall2.4/tier1.stl
80.0 x 100.0 x 224.0

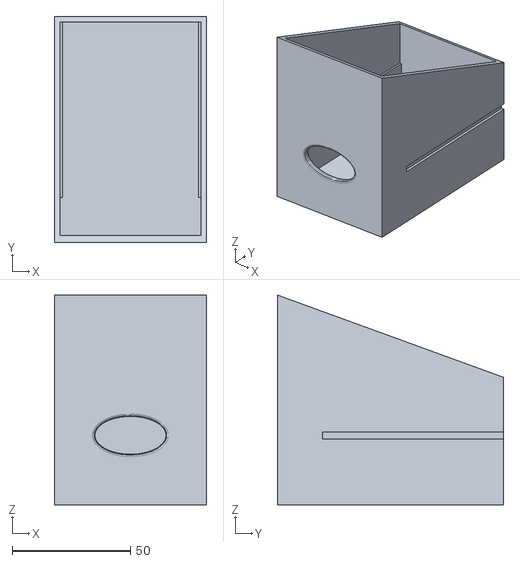
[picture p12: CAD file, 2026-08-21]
output/w70-wall2.4/drawer.stl
64.4 x 95.6 x 88.7

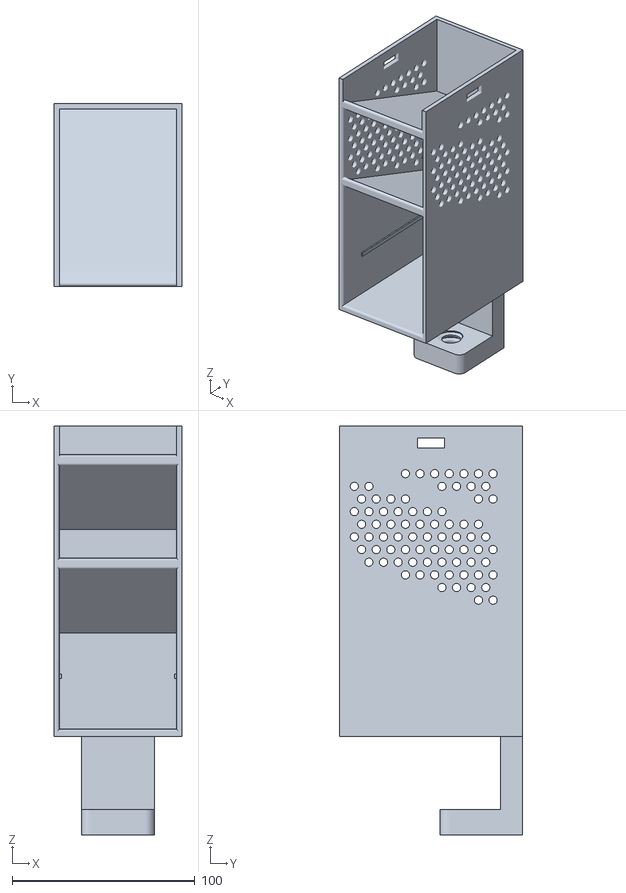
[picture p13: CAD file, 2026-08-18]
output/w70-wall3.0/tier1-drawer.stl
70.0 x 100.0 x 224.0

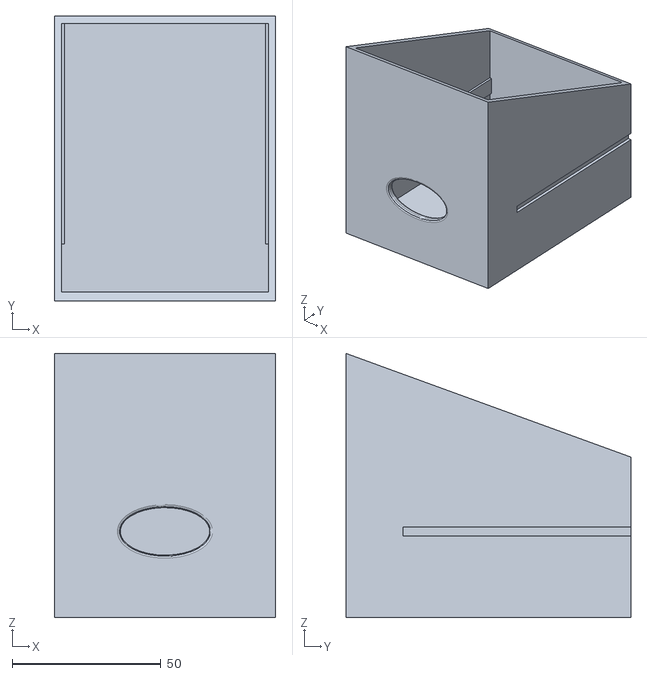
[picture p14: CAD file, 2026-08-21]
output/w80-wall2.4/drawer.stl
74.4 x 95.6 x 88.7

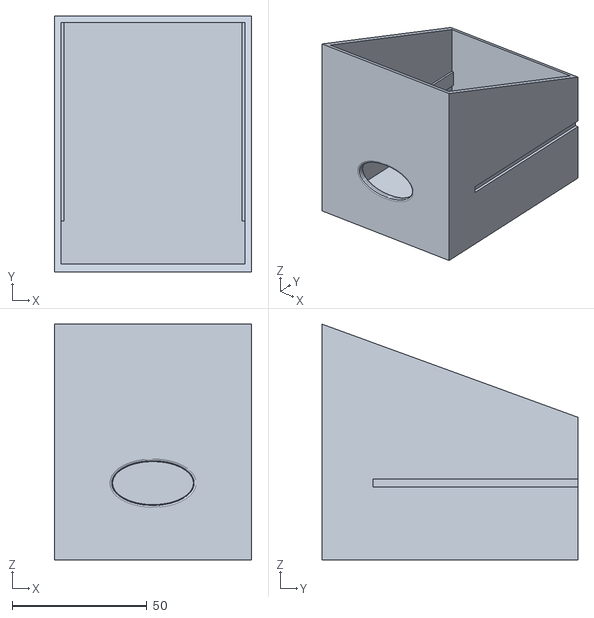
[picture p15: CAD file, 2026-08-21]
output/w80-wall3.0/drawer.stl
73.2 x 95.0 x 87.5

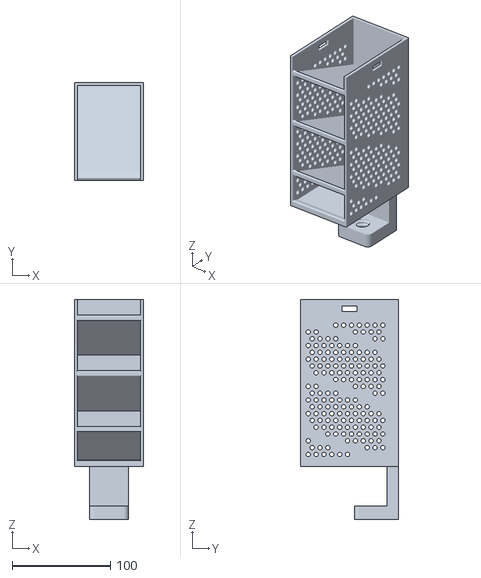
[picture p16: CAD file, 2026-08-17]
output/w70-wall3.0/tier1.stl
70.0 x 100.0 x 224.0

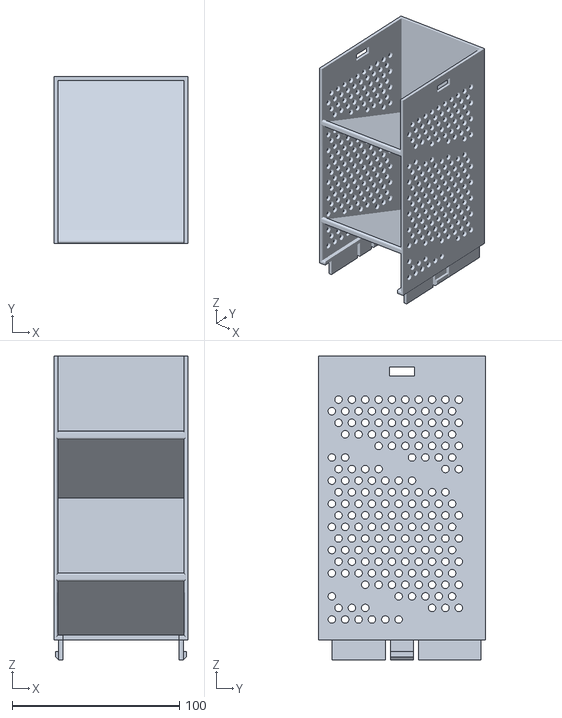
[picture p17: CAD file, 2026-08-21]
output/w80-wall2.4/module2.stl
80.0 x 100.0 x 182.0

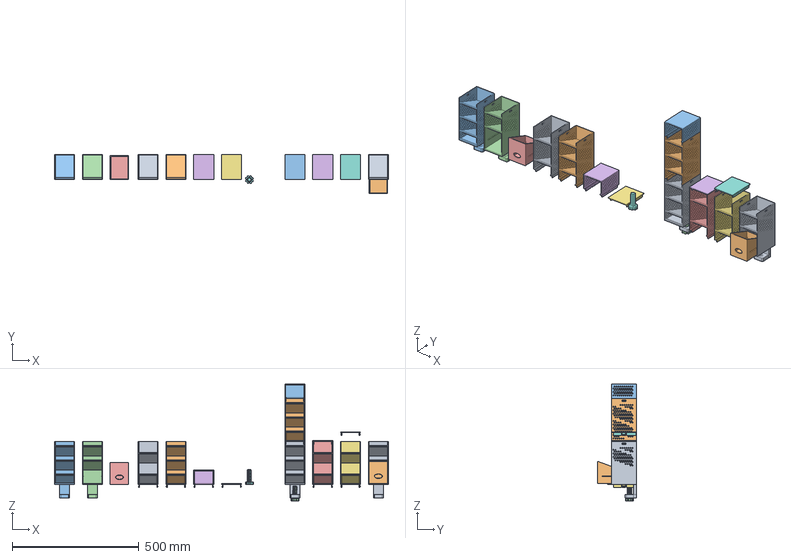
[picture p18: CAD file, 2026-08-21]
output/w80-wall3.0/pen_holder.FCStd
1320.0 x 155.0 x 461.7 mm
module2
module3
tier1
tier1_drawer
drawer
topmodule
lid
thumbscrew
asm_tier1
asm_module3
asm_topmodule
asm_screw
asm_module2
asm_lid
exp_module2
exp_lid
exp_tier1d
exp_drawer

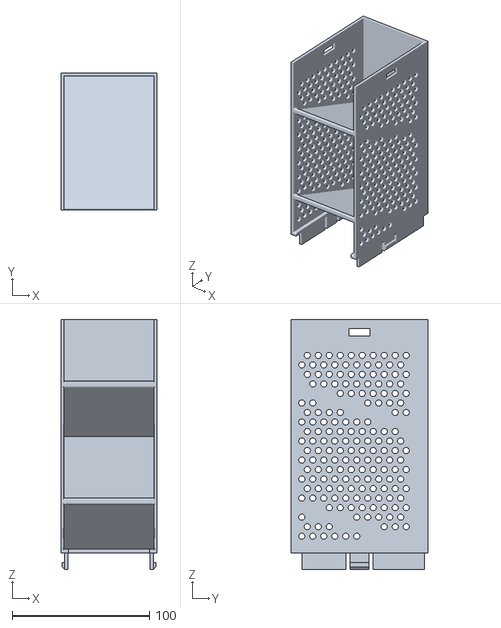
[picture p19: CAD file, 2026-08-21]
output/w70-wall2.4/module2.stl
70.0 x 100.0 x 182.0

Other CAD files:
output/w70-wall3.0/pen_holder.FCStd
output/w80-wall3.0/tier1.stl
output/w70-wall2.4/tier1-drawer.stl
output/w80-wall2.4/tier1-drawer.stl
output/w70-wall2.4/fixed-drawer.3mf
output/w70-wall2.4/module3.stl
output/w70-wall2.4/thumbscrew.stl
output/w70-wall2.4/tier1.stl
output/w70-wall2.4/topmodule.stl
output/w70-wall3.0/lid.stl
output/w70-wall3.0/module2.stl
output/w70-wall3.0/module3.stl
output/w70-wall3.0/thumbscrew.stl
output/w70-wall3.0/topmodule.stl
output/w80-wall2.4/module3.stl
output/w80-wall2.4/pen_holder.FCStd
output/w80-wall2.4/thumbscrew.stl
output/w80-wall2.4/topmodule.stl
output/w80-wall3.0/fixed-drawer.3mf
output/w80-wall3.0/lid.stl
output/w80-wall3.0/module2.stl
output/w80-wall3.0/module3.stl
output/w80-wall3.0/thumbscrew.stl
output/w80-wall3.0/topmodule.stl

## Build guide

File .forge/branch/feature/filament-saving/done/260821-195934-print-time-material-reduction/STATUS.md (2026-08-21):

# STATUS — 출력 시간·필라멘트 절감
slug: print-time-material-reduction
status: done
executed: 2026-08-21
completed: 2026-08-21
verified: yes (검증 32항목 PASS + 재료 실측 세트 601→511cm³·전량 1066→894cm³ / 시간은 CLI가 실행 중 GUI에 막혀 미실측 — 계획의 대안 조항대로 사실·절차를 run.md에 기록)
retro: skipped (fg-next all 자동 드라이브 — 학습은 run.md에 남고 승급은 이후 fg-learn으로 미룸)
docs updated: README 출력 최적화 절·비호환 경고

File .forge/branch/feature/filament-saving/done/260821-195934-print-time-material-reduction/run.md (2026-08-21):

<!-- forge-slug: print-time-material-reduction -->
# 실행 기록 — 출력 시간·필라멘트 절감

## 조각별 결과
- S1 모델 파라미터 축소(벽 2.4 / 선반·바닥 3.0) + 스냅 물림 가드 검증 추가 — ✅ 계획대로
- S2 출력 시간·필라멘트 실측 — ⚠ **미달**: BambuStudio CLI가 실행 중인 GUI에 막혀 슬라이싱 불가. 계획의 대안 조항(추정치로 대체하지 않고 사실·절차 기록)으로 처리
- S3 README 출력 최적화 절 + 비호환 경고 + 치수·검증 수치 정정 — ✅ 계획대로

## 계획대로 된 것
- `WALL` 3.0→2.4, `BOT_T`·`SHELF_T` 4.0→3.0. 검증 **32항목 전부 PASS** — 필렛 r1.4, 앞턱 램프 53.5°, 스냅 물림 1.55mm, 서랍·레일 공차가 모두 유지됨.
- 재료 실측(실사용 5부품 세트): **601 → 511cm³ (745g → 634g, −15%)**. 8부품 전량은 1,066 → 894cm³.
- 신규 검증 항목 `snap wall guard` 추가 — 벽을 더 얇게 하면 스냅 돌기가 벽을 관통하거나 물림이 사라지는 관계를 계산으로 고정(현재 관통 여유 0.85mm).
- README: 출력 최적화 절(부품 선택 −43% 실측표·서포트 OFF·레이어 0.28·wall_loops 3·시간 측정 명령), 버전 간 비호환 경고, 치수·파라미터·검증 수치 정정.

## 현장 결정 (계획에 없던 판단)
- **사용자 질문으로 우선순위를 재검토했다.** "모델 수정이 꼭 필요한가"라는 지적을 받아 레버를 분해해 보니, 모델 수정(−15%)은 네 레버 중 가장 작고 유일하게 대가(강성 −20%, 기존 3.0mm판과 비호환)를 치르는 레버였다. 범위 조정(−43%)과 레이어 높이가 더 크고 대가가 없다. 사용자가 "이미 바꿨으면 유지"로 확인해 유지했으나, 이 우선순위는 문서에 반영했다(README에서 부품 선택을 1번, 벽 두께는 파라미터 표로만).
- 타공 확대는 그릴링 단계의 실측(−1%)대로 기각 유지.
- 시간 절감은 README에서 **수치 없이 방향만** 기술하고 "이 프로젝트에서 실측하지 못했음"을 명시했다. 통설(25~30%)을 측정치처럼 쓰지 않았다.

## 막혔던 곳 / 학습
1. **BambuStudio CLI는 GUI가 실행 중이면 동작하지 않는다.** `Initializing StaticPrintConfigs`에서 멈춘 뒤 타임아웃(종료코드 124). `--datadir`로 설정 디렉터리를 분리해도 우회되지 않았다. 사용자가 다른 프로젝트를 열어 작업 중이었으므로 앱을 강제 종료하지 않았다 — 측정보다 사용자의 작업 보존이 우선이다.
2. **CLI에 사용자 프로파일을 그대로 먹일 수 없다.** 3mf의 `Metadata/project_settings.config`는 병합된 프로젝트 설정이라 `--load-settings`가 `from project unsupported`로 거부한다. 내장 프리셋(machine/process/filament json)을 각각 지정해야 하며, 그러면 절대 시간이 사용자 환경과 달라진다.
3. GUI가 열리기 전 성공한 1건: 신규(2.4mm) `topmodule` = **7시간 2분 / 필라멘트 17.55m** (CLI 기본 프로파일, 레이어 0.2·벽 2줄·인필 20%·서포트 없음). 단일 표본이고 사용자 프로파일(외벽 200~350mm/s)과 다르므로 30시간과 직접 비교할 수 없다.

## 다음 단계 (검증 범위 외)
- 시간 실측 재개 절차: BambuStudio를 닫고 `--slice 0 --arrange 1 --outputdir ... --export-3mf ...`로 `/tmp/baseline`(3.0mm)과 `output/`(2.4mm)을 같은 조건으로 슬라이싱해 `estimated printing time`을 비교. 기준 STL은 `/tmp/baseline`에 보존돼 있으나 임시 디렉터리이므로 재부팅 시 사라진다 — 필요하면 `git show 0714ae4:output/module3.stl` 등으로 되살릴 수 있다.
- 서포트 ON/OFF 차이도 같은 방법으로 측정하면 README의 "서포트 끄기" 권고에 수치를 붙일 수 있다.

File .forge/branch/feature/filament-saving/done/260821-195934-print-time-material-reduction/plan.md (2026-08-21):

<!-- forge-slug: print-time-material-reduction -->
<!-- task: 3 -->
<!-- tdd: off -->
# 출력 시간·필라멘트 절감 (품질 유지)

## 목표 / 비목표
- 목표: 8부품 전량 출력 기준 30시간이 걸리는 현재 상태에서, 형상 품질과 적층 강성을 유지한 채 **재료를 실측 기준으로 절반 이하로**, **출력 시간을 실측으로 확인 가능한 만큼** 줄인다. 모델 파라미터 변경 + 슬라이싱 설정 안내를 함께 산출한다.
- 비목표: 타공 확대(측정 결과 1% 절감뿐이라 기각), 강도 FEA 해석, 부품 인터페이스 재설계(스냅·클램프·서랍 레일 치수 불변), 다른 프린터·필라멘트 프로파일 튜닝, 부품 삭제.

## 그릴링에서 실측한 사실 (근거)
- 8부품 전량 = **1,066cm³ / 1,322g**. 이 중 `tier1`과 `tier1-drawer`는 **대체 부품**이고 `module2`/`module3`도 변형이라, 실사용 한 세트(1단서랍형+서랍+3칸+마감+나사)는 **601cm³ / 745g = 전량의 56%**.
- 벽 2.4 / 선반·바닥 3.0 으로 낮추면 세트가 **511cm³ (−15%)**, 검증 31항목 전부 통과. 이때도 필렛 r1.4·스냅 물림 1.55mm·앞턱 램프 53.5°가 유지됨(실측).
- 타공을 Ø6·피치 9.5로 키워도 벽 두께가 같으면 511 → 506cm³(**−1%**)뿐 → 기각.
- 사용자 3mf 설정 실측: 레이어 0.2 / 노즐 0.4 / wall_loops 2 / 인필 15% grid / **서포트 tree(auto) ON** / `support_on_build_plate_only=0` / 8개 플레이트.

## 확정 사양 (그릴링 합의)
- **모델**: `WALL` 3.0→**2.4**, `BOT_T` 4.0→**3.0**, `SHELF_T` 4.0→**3.0**. 클램프(`PLATE_T`/`JAW_T`)·스커트(`SKIRT_T`)·서랍 벽(`DRAWER_WALL`)·레일은 별도 파라미터라 **불변**.
- **호환성**: 벽 두께는 적층 인터페이스의 기준선이라, 2.4mm판은 기존 3.0mm판과 **섞어 쓸 수 없다**(구형 스커트가 좌우 각 0.85mm 헐거워지고 캐치 물림이 1.55→0.95mm로 감소). 호환을 포기하고 **문서에 경고를 명시**한다.
- **타공**: 현재 Ø4.5·피치 8.0 그대로.
- **슬라이싱 안내(문서 산출물)**: ① 실사용 세트만 출력(부품 선택 표) ② **서포트 OFF** — 뒷면 안착 방향에서 남는 하향면은 타공 구멍 상단 아치와 나사산뿐이고 둘 다 브리징 범위 ③ 레이어 0.2→**0.28** ④ 2.4mm 벽에서는 **wall_loops 3** 권장(벽이 솔리드로 차 강성을 회복, 갭 필 아티팩트 제거).
- **검증 강화**: 벽을 더 얇게 만들 때 조용히 깨지는 관계를 검증 항목으로 고정 — 스냅 돌기가 벽을 관통하지 않을 여유(`WALL − (BUMP_D − CLEAR) ≥ 0.5`)와 최소 물림(`BUMP_D − CLEAR ≥ 1.0`).

## 진실의 원천
- 용어: `.forge/CONTEXT.md`의 적층 모듈 · 스냅핏 클립 · 경사 칸 · 앞턱 · 서랍 구간
- 관련 ADR: 없음 (파라미터 변경으로 되돌릴 수 있어 기준 미달)
- 완료 정의(DoD): (a) `freecadcmd pen_holder.py` 검증 전항목 PASS(신규 스냅 관통 가드 포함, 필렛 r1.4 유지), (b) 실사용 세트 재료가 601→**511cm³ 부근(±10)** 으로 실측되고 그 수치가 문서에 반영, (c) **BambuStudio CLI로 개선 전/후를 슬라이싱해 상태 출력 시간과 필라멘트 사용량을 실측**하고 비교표를 남김 — CLI가 동작하지 않으면 그 사실과 사용자 측 슬라이싱 절차를 `run.md`에 기록(추정치로 대체하지 않는다), (d) README에 출력 최적화 절과 3.0mm판 비호환 경고가 들어가고 옛 수치(벽 3.0·선반 4.0)가 남지 않음.

## 작업 조각
- [ ] S1. 모델 파라미터 변경(`WALL` 2.4 / `BOT_T`·`SHELF_T` 3.0) + 스냅 관통·물림 가드 검증 항목 추가 — 완료 기준: 검증 전항목 PASS(필렛 r1.4 유지 확인), 세트 재료 실측 511cm³ 부근
- [ ] S2. 출력 시간·필라멘트 실측 — BambuStudio CLI(`--slice`)로 변경 전 STL과 변경 후 STL을 동일 설정으로 슬라이싱해 상태 시간·사용량을 뽑고, 서포트 ON/OFF 차이도 함께 측정 — 완료 기준: 전/후·서포트 유무 수치가 담긴 비교표 산출, 또는 CLI 실패 시 그 사실과 대체 절차 기록 (depends: S1)
- [ ] S3. README 갱신 — 출력 최적화 절(부품 선택 표·서포트 OFF·레이어 0.28·wall_loops 3·실측 절감치), 3.0mm판 비호환 경고, 치수·파라미터 표 정정 — 완료 기준: 실측값이 반영되고 옛 수치 잔존 0, 링크·이미지 무결 (depends: S2)

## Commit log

2026-08-17 적층형 경사 필통 FreeCAD 파라메트릭 모델 추가
    - pen_holder.py: 적층 모듈·1단(책상 클램프+암나사)·썸스크류 3부품 생성 스크립트
    - 경사 2칸(20°) + 하단 전면 개방 포켓, 스냅핏 적층, 나사 규격은 참고 STL 실측 호환
    - output/: 검증(9항목 PASS)된 STL 3종 + FCStd
    - reference/: 업로드 참고 STL 보존
    - .forge/: 용어집(CONTEXT.md)과 스냅핏 채택 ADR
    [clamp-reference.stl, module.stl, pen-holder-reference.stl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]
2026-08-17 적층 모듈 하단 개방 — 적층 시 아래 칸과 공간 연결
    - make_body(bottom_open) 분기: 모듈은 하단 포켓 바닥판·앞턱 제거,
    측벽 안쪽 3mm 바닥 레일(FLANGE)만 존치해 스냅 스커트 부착 유지
    - tier1은 바닥 유지 (책상 위 최하단)
    - freecadcmd 재검증 9항목 PASS, 단면 점검으로 개방·레일 확인
    [module.stl, pen_holder.FCStd]
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2026-08-17 앞면 필렛·클램프 플러시·칸 수 변형(2/3칸) 추가
    - 앞쪽 모서리 필렛 r1.4 (적층 연결부 z=0/170 접촉 모서리는 결합면
    평면 유지를 위해 제외)
    - tier1 클램프를 뒷면 평면과 플러시로 이동 — FDM 등면 안착 출력 대응
    (PLATE_UP 보강 제거, 두께 유지)
    - 칸 수 파라미터화: tier1은 3칸, 적층 모듈은 module2(2칸)/module3(3칸)
    두 변형. 높이 170 공통으로 적층 인터페이스 호환, module.stl 대체
    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
    [module.stl, module2.stl, module3.stl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]
2026-08-17 측벽 벌집 타공 패턴 추가 (빈 영역 자동 회피)
    - Ø4.5·피치 8mm 스태거드 배열, X관통 원기둥으로 양 측벽 동시 타공
    - 선반 슬래브 띠·캐치 창·상하 결합부·앞뒤 가장자리 자동 회피
    (부품별 칸 배치에 맞춰 산출: 2칸 169개, 3칸 153개)
    - PERFORATE/PERF_D/PERF_PITCH 파라미터화, 검증 12항목 PASS
    [module2.stl, module3.stl, pen_holder.FCStd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]
2026-08-17 앞턱을 자기지지 램프로 변경 — 서포트 없이 출력 가능하게
    - 앞턱 뒷면의 수직 단차(폭 74×6mm 하향 천장)가 뒷면-아래 출력 시
    칸마다 서포트를 유발 → 높이 3mm·기저 8mm의 53.5° 램프로 대체
    - 베드에서 3.25mm 떠 있던 뒷면 스커트 판 제거 (깊이 위치 결정은
    측면 스커트 뒤끝이 담당)
    - 광선투사 실측: 앞턱 1669→104 / 2050→104mm², 스커트 882→60mm²,
    합계 6100→3713(module3) · 5587→3641(tier1) mm²
    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
    [module2.stl, module3.stl, pen_holder.FCStd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]
2026-08-17 README 작성 + FCStd 배치·스크린샷 생성 스크립트 추가
    - README.md: 스크린샷 4장 배치, 부품 4종·치수 사양·조립 순서·주요
    파라미터·파일 구조 정리. 출력 가이드에 방향별 실측 서포트 면적을
    근거로 넣어 "뒷면을 베드에" 지시의 이유를 명시
    - pen_holder.py: 부품을 FCStd 안에서 나열 뷰 + 조립 뷰(tier1+module3
    적층·썸스크류 체결)로 배치. Placement는 STL 내보내기 이후에만
    적용해 출력물은 원점 유지
    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
    [pen_holder.FCStd]
2026-08-17 폭 70mm 전환 + 마감 모듈·뚜껑 추가, 8cm판은 output-8cm으로 보존
    - 폭 80→70mm (출력해보니 넓었음). 8cm 산출물 일체를 output-8cm/에 보존
    - 마감 모듈(topmodule): 바닥 없이 아래 칸과 공간이 이어지고 천장이
    일체로 붙은 한 부품, 높이 56.7mm(=3칸 모듈의 한 칸)
    - 평판 뚜껑(lid): 모듈 바닥과 동일한 스냅 스커트라 2칸·3칸 모듈 위에
    그대로 결합
    - 뚜껑 분해도 스크린샷 추가(shot-lid-open.png), screenshot.py 가시성을
    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
    [lid.stl, module2.stl, module3.stl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]
2026-08-17 슬라이서 프로젝트(3mf) 2종 추가 + .gitignore
    - output/fixed-drawer.3mf (7cm용), output-8cm/fixed-drawer.3mf (8cm용)
    — 각 STL 세트 옆에 용도별 슬라이싱 설정 보관
    - .gitignore: .DS_Store, __pycache__/ (파이썬 바이트코드 캐시)
    [fixed-drawer.3mf]
2026-08-17 클램프 체결 개선: 나사 25mm 연장 · 아래턱 10mm 축소 · 나사 빨강 표시
    - 썸스크류 나사부 22→47mm. 기존 길이로는 아래턱 위로 10mm만 올라와
    두께 30mm 미만 상판에 닿지 않아 사실상 체결 불가였음
    (체결 가능 두께 30~40mm → 5~40mm)
    - 같은 결함을 다시 놓치지 않도록 '체결 가능 상판 두께' 검증 추가
    (검증 20항목)
    - 아래턱 돌출 55→45mm, 앞 끝 좌우 모서리 r5 필렛 (나사산 절삭 전에
    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
    [pen_holder.FCStd, thumbscrew.stl, tier1.stl]
2026-08-17 슬라이서 프로젝트 갱신 (7cm판)
    [fixed-drawer.3mf]
2026-08-17 참고 STL 제거 (설계 실측만 주석으로 유지)
    - reference/ 삭제. 실측으로 정한 값(벽 3mm·바닥 4mm·경사 20° 등)은
    파라미터 주석에 그대로 남아 재생성에 지장 없음
    - 파일을 가리키던 주석·README 파일구조 정리
    [clamp-reference.stl, pen-holder-reference.stl, pen_holder.FCStd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]
2026-08-17 라이센스 적용: 코드 MIT · 도면 CC BY-SA 4.0
    - LICENSE(MIT): pen_holder.py, screenshot.py
    - LICENSE-MODELS(CC BY-SA 4.0): output/·output-8cm/의 STL·FCStd·3MF·렌더
    CC 원문은 정확성을 위해 공식 URL 참조 (요약 + 적용 범위 + 출처 표기 예시)
    - README에 라이센스 절 추가
    - .gitignore: FreeCAD 백업(*.FCBak) 추가
2026-08-17 클램프 폭 60→40mm 축소 + 구멍 주변 재료 검증 추가
    - 체결부가 필요 이상으로 넓어 양옆 10mm씩 축소
    - 검토 결과 안전: 구멍(Ø19.3) 양옆 재료 10.3mm, 가혹 조건(3kg·팔길이
    100mm) 굽힘응력 3.1MPa로 PLA 항복 대비 16배 여유
    - 더 줄이면 구멍 주변이 먼저 위험해지므로 '구멍 주변 재료 ≥8mm'
    검증 추가 (폭 36mm 미만이면 FAIL) — 검증 21항목
    [pen_holder.FCStd, tier1.stl]
2026-08-18 작업 #1 봉인: 회고 작성 + 용어집 갱신
    - 회고: FreeCAD/OCC 함정 4건(removeSplitter 무효화, common() 조용한
    실패, BoundBox 과대추정, exportStl ASCII)과 "치수 검증은 쓸 수 있는지를
    답하지 않는다"는 교훈 기록
    - CONTEXT.md: 퀵 작업 누적으로 어긋난 정의 정정(경사 칸 가변 칸 수, 폭
    70mm, 클램프 체결 범위) + 마감 모듈·평판 뚜껑·앞턱 신규 등재
    - 활성 슬롯을 .forge/done/260818-133541-stackable-angled-pen-holder/로 아카이브
    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
2026-08-18 tier1-drawer 변형과 서랍 부품 추가 (쐐기형·가드 레일)
    - tier1-drawer: 기존 tier1은 그대로 두고 make_tier1(drawer=True) 분기로
    최하단 칸을 서랍 구간으로 개방. 위 2칸·클램프·상단 캐치는 동일
    - drawer: 경사 천장을 따르는 쐐기 상자(앞 87.5→뒤 52.9mm). 앞판이 개구
    전체 높이를 덮어 내부 용적 약 350cm³
    - 손가락 개구 30×16mm를 빈 서랍의 CenterOfMass 높이에 배치 — 당김점·
    무게중심·레일이 한 선에 놓여 기울임 모멘트 0. 모서리 r1.0 라운딩
    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
    [drawer.stl, fixed-drawer.3mf, pen_holder.FCStd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]
2026-08-18 작업 #2 봉인: 회고 작성 + 용어집 갱신
    - 회고: 형태 선택은 렌더로 물을 것(사각→쐐기 재실행 1회), 치수를 상수로
    박지 말고 솔리드에서 유도할 것(중앙 43.8 vs 무게중심 29.0), 검증 코드
    자체도 검증할 것, Part.Compound에 CenterOfMass 없음
    - CONTEXT.md: 서랍 구간·서랍 정의를 쐐기형 기준으로 정정, 레일 신규 등재
    - .forge/done/260819-010247-tier1-drawer-variant/ 로 아카이브
2026-08-18 슬라이서 프로젝트 갱신 (서랍 부품 반영)
    [fixed-drawer.3mf]
2026-08-18 슬라이서 프로젝트 갱신
    [fixed-drawer.3mf]
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2026-08-21 벽·선반 두께 축소로 재료 15% 절감 + 출력 최적화 문서화
    - WALL 3.0→2.4, BOT_T·SHELF_T 4.0→3.0. 실사용 세트 재료 601→511cm³
    (745g→634g), 8부품 전량 1066→894cm³
    - 검증에 'snap wall guard' 추가 — 벽을 더 얇게 하면 스냅 돌기가 벽을
    관통하거나 물림이 사라지는 관계를 계산으로 고정 (검증 32항목)
    - README 출력 최적화 절: 필요한 부품만 뽑기(실측 −43%)를 1순위로,
    서포트 OFF, 레이어 0.28, wall_loops 3, 시간 측정 명령
    - 버전 간 비호환 경고 — 2.4mm판과 기존 3.0mm판은 스택을 섞을 수 없음
    (스커트 0.85mm 유격, 스냅 물림 1.55→0.95mm)
    - 스크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
    [drawer.stl, fixed-drawer.3mf, lid.stl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]
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2026-08-21 출력물을 4개 변형(폭 × 두께) 폴더로 분리 생성
    - VARIANTS 테이블 + set_variant() — 한 번 실행하면 w70/w80 × wall2.4/3.0
    네 조합이 각자 폴더에 생성. wall3.0은 예전 두께 전체 복원(선반·바닥 4.0)
    - 변형당 33항목 × 4변형 = 132개 PASS. 신규 'variant params'가 변형마다
    IN_D == D-WALL 정합을 확인 (파생 상수를 놓쳐 조용히 틀어지는 것 방지)
    - 변형별 세트 재료 실측: 511 / 548 / 601 / 646cm³ (내용 동일 사고 방지)
    - output-8cm/ 폐지 → w80-wall3.0/으로 대체. 사용자 슬라이서 프로젝트
    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
    [drawer.stl, fixed-drawer.3mf, lid.stl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]
